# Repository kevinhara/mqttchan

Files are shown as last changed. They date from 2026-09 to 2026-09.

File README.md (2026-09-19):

# mqttchan

A desk notification device: an ESP32 with two 128x64 OLEDs — one showing an
animated avatar face, one showing message text as a typed-out speech bubble —
plus an RGB status LED and a piezo for notification jingles.

This repository holds the whole system: the firmware, the broker config, and the
services that send it messages.

```
   feeds ──HTTP──▶ services/api ──MQTT──▶ broker ──▶ firmware (the device)
(what happened)   (how it looks,        (mosquitto      (renders it)
                   how often)            on osmo)
```

| Directory | What it is |
|---|---|
| [`firmware/`](firmware/) | PlatformIO ESP32 firmware. Flash with `cd firmware && pio run -t upload` |
| [`broker/`](broker/) | mosquitto config, deployed to osmo |
| [`services/`](services/) | TypeScript: the API layer and the feeds that talk to it |
| [`docs/`](docs/) | The control page at [mqttchan.kev.nz](https://mqttchan.kev.nz), served by GitHub Pages |

## Why feeds don't publish to MQTT themselves

Feeds POST a *semantic* message to the API — "this happened, it's low priority"
— and the API alone decides how it looks and when it is shown. Nothing but the
API connects to the broker.

That split earns its keep in two places:

- **The device contract can change without touching a feed.** It already has:
  contract v2 made expressions case-insensitive and gave `led` arbitrary hex
  colors, and no feed needed to know.
- **The device is slow, and one place has to know that.** It shows one message
  at a time and holds it ~30s after typing it out, so it absorbs roughly one
  message per 35 seconds — and its own queue is unbounded, so once you overrun
  it, it never catches up. The API paces publishes to the device's real speed,
  collapses repeated readings of the same thing, drops stale messages, and lets
  genuine alerts jump the queue.

## Status

Built, deployed and verified on hardware 2026-09-17:

- **Contract v2 is flashed and verified on the device** (`Ziggy`, `10.0.0.114`).
  Firmware is at 45.8% of the 3MB app partition. Checked against serial with a
  negative control, so silence means parsed rather than merely unobserved:

  | Payload | Serial |
  |---|---|
  | `happy` + `#ff8800` + `Chime` | silent — v2 forms all parse |
  | `Happy` + `red` + `chime` | silent — the old spellings still work |
  | `sleepy` + `cycle` | silent |
  | `ecstatic` + `#fff` + `kazoo` | all three warned and fell back |

  The `#fff` rejection is deliberate: only the exact 6-digit form parses, so a
  typo warns instead of being guessed at.
- **`services/api` is deployed on osmo** (`mqttchan-api`, port 8420) and
  connected to the broker. Verified publishing valid v2 payloads with pacing,
  dedupe by key, and high-priority messages overtaking queued ambient ones.
- **The Python `avatar-brain` container has been stopped and removed** from
  osmo. Its source directory is left at `~/avatar-brain` there, so the
  decommission is reversible.
- 52 unit tests passing across the API, feed-kit and the flights feed.

**The first real feed is live: `feeds/flights`**, which announces arrivals and
departures at ZQN from live ADS-B. Deployed to osmo as `mqttchan-feed-flights`
and **confirmed end to end on real traffic 2026-09-18**: at 09:20 NZST it
published `ZKICH left ZQN` — one message, no duplicate, queue drained, device
connected throughout. The API paced and published it unchanged, and triage
rendered `kind: "notice"` as
`{"expression":"happy","led":"#3399ff","blink":false,"jingle":"chime"}`.

The detector was also validated offline against a real arrival before deploy: a
captured 15-snapshot approach (ANZ611 descending 5550ft at 11.8nm through to
on-the-ground at 0.27nm), replayed, announces `ANZ611 landed at ZQN` exactly
once and stays silent either side of it.

**Correction, 2026-09-18 (same day):** the line above briefly said a departure
was "not yet seen live", which was true for about twenty minutes after deploy.
`ZKICH left ZQN` settled it. Both directions of the edge are now confirmed
against real aircraft, which is worth stating plainly because the departure
path is the one that had only unit tests behind it.

**Correction, 2026-09-18:** this section previously said the first real feed
would be Home Assistant temperature readings. That was the plan and the HA
research had already been done; the flights feed was simply what got built
first. The HA work is still queued and still valid — see
[`services/README.md`](services/README.md).

**Correction, 2026-09-19:** contract v3 removed `expression` entirely — the
`happy`/`angry`/`sad`/`doubt`/`sleepy`/`neutral` vocabulary above and the
`{"expression":"happy",...}` triage output a few lines up are v2 history, not
current behavior. The field had already stopped doing anything the moment the
firmware's portrait pack replaced m5avatar's procedural eyes/mouth (contract
v2's expressions had nowhere left to apply); v3 just stopped sending and
validating it. `led`, `blink` and `jingle` are unaffected.

`feeds/example` remains a template, left disabled behind a compose profile.

## Deploy

```
cd firmware && pio run -t upload                      # the device
scp -r broker kevin@osmo:~/mosquitto                  # the broker
scp -r services kevin@osmo:~/mqttchan-services        # the API and feeds
ssh kevin@osmo 'cd ~/mqttchan-services && docker compose up -d --build'
```

`services/.env` is not in git — copy `services/.env.example` on the host and
fill it in.

## History

The broker config and a Python publisher called `avatar-brain` used to live in
`~/Homelab/osmo/`, which is not a git repository. Both moved here on
2026-09-17: the broker config unchanged, and `avatar-brain` superseded rather
than migrated — it had been running on osmo for weeks in a dormant state, with
no entities configured and an expired token, and had never published anything.
Stubs in the old Homelab directories point here.

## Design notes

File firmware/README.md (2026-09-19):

# mqttchan firmware

**Moved 2026-09-17** from the repository root into `firmware/`, when the
firmware, the broker config and the new TypeScript services were collapsed into
one monorepo. Nothing in the build changed — but **the flash command is now
`cd firmware && pio run -t upload`**, not `pio run -t upload` from the repo root.
Paths quoted throughout this file (`include/...`, `src/...`) are still relative
to this directory and remain correct; `../docs/index.html` is the exception,
since the control page stays at the repo root for GitHub Pages.

This file used to be titled "avatar-demo", after the project this started as.
The device is called mqttchan; `avatar/say` remains the MQTT topic.

**Correction, 2026-09-18:** this file used to say `m5stack-avatar` "remains
the rendering library" and described the face panel throughout as procedural
eyes/mouth driven by `Avatar::setExpression()`/`setMouthOpenRatio()`. That's
no longer true: the face panel now shows a random bitmap portrait from the
bundled "1-bit dialogue portraits" pack instead (`include/portrait_face.h`,
`include/portraits_data.h`) - a slow "breathing" bob while idle, punctuated
every few seconds by a quick blink (added 2026-09-19). Every character
blinks, using the exact same mechanism for all 99: `Portrait::blink`, a
frame `firmware/tools/gen_portraits.py` synthesizes for every character
(`_SYNTHETIC_BLINKS`, one dict entry per character) by closing an eye region
hand-picked against that character's own art and cutting a thin line back
through it - kept entirely separate from the pack's own `frames`/
`frameCount`, which are unchanged and still only drive the talk-time mouth
flap (`advanceTalkFrame()`).

**Correction, same day:** two earlier passes at this got it wrong before
landing here. First pass gave the two single-frame characters (44/portrait
112, 66/portrait 156) a head-nod instead of a blink, since they had no
second frame to flash to - not what was asked for. Second pass "fixed" that
by synthesizing a real second frame for just those two, but left every other
character blinking by flashing to its own frame 1 - which, on a live board,
turned out to be a mouth-open frame for a large fraction of the pack, so
idle was visibly opening its mouth instead of blinking. Every character now
gets a synthesized `blink` frame, not just the two that had no frame 1 to
reuse in the first place - the reuse was the bug, not just the exception
list around it. Cycles through that character's own 1-4 talk frames while a
message types, and a new random character is picked each time an
announcement finishes. Build-verified and QA'd via a rendered contact sheet
of all 99 blink frames against their originals - not yet looked at on the
board. `m5stack-avatar`
and its `Avatar.h`/`SmallOledFace` are gone from the build entirely
(`platformio.ini`'s `lib_deps` no longer pulls it in). The old reading was
believable because it was true from this project's start through
2026-09-17 - this is a deliberate swap, not a regression. The rest of this
document (core split, MQTT contract, expressions, demo mode) was written
against the old library and has not been fully re-verified against the new
one; `include/portrait_face.h`, `include/mqtt_link.h` and `src/main.cpp` are
the current source of truth where the two disagree. **Update, 2026-09-19:**
"expression" no longer appears in the MQTT payload at all - contract v3
removed the field entirely (it had been parsed-and-warned-on but otherwise
inert since the portrait swap above; see **Contract v3** under "MQTT-driven
mode" below).

[stack-chan/m5stack-avatar](https://github.com/stack-chan/m5stack-avatar) used
to run on a bare ESP-WROOM-32 with a 128x64 SSD1306 I2C OLED — no M5Stack
hardware involved; see the correction above for what replaced it. A second
SSD1306 shows what's "said" as a word-wrapped speech bubble (see "The speech
bubble" below) — optional, and everything below runs fine without it wired
up.

By default the board joins WiFi, subscribes to an MQTT topic, and drives the
avatar + bubble from whatever `{"text":..., "led":..., ...}` JSON arrives
(see "MQTT-driven mode" below, including **Contract v3**'s removal of
`"expression"`) — this is meant to run against the `services/api` layer in
this repo, not standalone. (It previously ran against a Python `avatar-brain`
service in the homelab; that has been superseded — see the root README.)
Build with `-DAVATAR_DEMO_MODE` instead to get the old self-cycling bench
demo (cycles six placeholder phrases, fakes lip-sync babble on every third
one) with no network required.

Verified live 2026-09-14 on ESP32-D0WDQ6 rev v1.0 (`/dev/cu.usbserial-0001`):
demo mode renders all six expressions correctly, heap flat at ~295 KB across
9 cycles, no reboots. MQTT mode verified the same day via the headless bench
test described below (no live broker was up yet): WiFi correctly times out
and retries rather than hanging when `secrets.h` has placeholder credentials,
and a synthetic payload correctly renders both the Happy expression and a
two-line-wrapped bubble.

## Core split

This was the reason for building it — the avatar gets one core, the other
stays free for application work.

| Core | Owner | What runs there |
| --- | --- | --- |
| 1 (`APP_CPU`) | the avatar | `drawLoop` + `facialLoop` (blink, saccade, breath) |
| 0 (`PRO_CPU`) | you | `appTask` — triggers, TTS, LLM calls, network |

The library already does most of this: `Avatar::start()` hardcodes both of its
tasks to `APP_CPU_NUM`, so no patching was needed. The part that _is_ on us is
that Arduino's `loop()` also runs on core 1 — so `loop()` is deliberately left
empty and all app logic goes in `appTask`, pinned to `PRO_CPU_NUM`. Putting
work in `loop()` would quietly land it on the avatar's core and fight the
renderer for time.

Cross-core calls into the avatar are safe for what the demo uses:
`setExpression()` suspends the draw task before mutating, and the float
setters (`setMouthOpenRatio`, gaze, breath) are single-word writes the draw
task only reads.

## Wiring

Two SSD1306 panels, **each on its own I2C bus** — they don't share pins:

| Panel | SDA | SCL | VCC | GND | Bus |
| --- | --- | --- | --- | --- | --- |
| Face (`oled`) | GPIO32 | GPIO33 | 3V3 | GND | software (bit-banged) I2C |
| Bubble (`oledText`) | GPIO4  | GPIO15 | 3V3 | GND | hardware I2C port 1 |

Both panels answer at the default address **0x3C** — no jumper needed, since
they're on physically separate buses and there's nothing to collide with.

**Corrected 2026-09-15:** this table used to pair Face with GPIO4/15
(hardware bus) and Bubble with GPIO32/33 (bit-banged) — the two physical
panels turned out to be mounted reversed relative to that wiring, so content
was landing on the wrong screen. `main.cpp` now builds `oled` on the
GPIO32/33 pins and `oledText` on GPIO4/15 instead (see the comment above
their declarations), which is the swap reflected in the table above. The
GPIO-level facts below (which pins to avoid and why) are about the physical
pins themselves and didn't change — only which panel/content each pin pair
drives did. Net effect: the avatar now runs on the slower 400kHz bit-banged
bus instead of the 800kHz hardware one; re-wiring instead of swapping in
software would recover that speed, but wasn't done here.

**Do not move GPIO4 (now the bubble panel's SDA) to GPIO2.** GPIO2 is a
boot-strapping pin; the OLED's pull-up on it holds the ESP32 out of USB
download mode (`Wrong boot mode detected (0x1b)`) and flashing fails whenever
the display is attached. Same lesson the sibling `hello-world` panel learned
on 2026-09-14. Port 1 (now the bubble panel's bus) is likewise deliberate:
M5Unified's `begin()` claims port 0 for its own PortA devices, and sharing it
means two drivers reconfiguring one peripheral with different pins.

**Why one panel is on GPIO32/33 instead of a second hardware port:** the
ESP32 classic only has two hardware I2C peripherals, and both are already
spoken for (port 0 by M5Unified, port 1 by the other OLED panel).
`SSD1306Display` in `ssd1306_display.h` passes its `i2c_port` argument
straight through to LGFX's `Bus_I2C`, which treats a **negative** port number
as a request for its bit-banged software I2C path (`soft_i2c.inl`) on
whatever GPIOs you give it — so `oled` in `main.cpp` is constructed with port
`-1` and pins 32/33. GPIO32/33 were picked because they're not
boot-strapping pins, not the SPI-flash pins (6-11), and not already claimed
by the other OLED panel or M5Unified. Clocked at 400kHz rather than the
hardware bus's 800kHz, since bit-banged timing is CPU-cycle-bound and less
forgiving at high speed.

## RGB status LED

A 4-pin RGB LED (3 color legs + 1 common leg), wired straight to the ESP32 —
no driver board, just a resistor per color leg.

| Leg | GPIO | Resistor  |
| --- | --- | --- |
| Red | GPIO25 | ~150–220Ω |
| Green  | GPIO26 | ~220–330Ω |
| Blue | GPIO14 | ~220–330Ω |
| Common | GND | none |

**Verified live 2026-09-16** on the same `/dev/cu.usbserial-0001` board:
wired common-cathode (common leg to GND), all three legs confirmed against
their GPIO via the `RGB_LED_TEST` build below — red/green/blue/off cycle and
a full HSV spectrum sweep both rendered the correct colors with no cross-talk
between channels.

**Put one resistor per color leg, not one shared resistor on the common
leg.** Each color die has a different forward voltage (red ≈2.0V,
green/blue ≈3.0V at 3.3V logic), so a single shared resistor over- or
under-drives whichever color has a different Vf, unevenly across channels.
The common leg itself needs no resistor — it's just the return path.

**This board is a 30-pin ESP32 devkit — GPIO16/17 aren't broken out**, unlike
on 38-pin boards where they usually are. GPIO25/26/14 were picked instead:
all three drive over LEDC PWM, and none collide with the OLED buses
(GPIO4/15, GPIO32/33), the piezo (GPIO27), the boot-strapping pins
(0/2/5/12), or M5Unified's reserved PortA pins (21/22 — see the comment in
`ssd1306_display.h`).

**If the LED turns out common-anode instead** (common leg to 3V3, not GND),
don't rewire it — `#define RGB_COMMON_ANODE` above the pin defines in
`main.cpp` inverts the PWM duty cycle in software instead.

**Building/rewiring on a breadboard-free case:** with Dupont jumpers jammed
straight into the 3D-printed case rather than a breadboard, splice each
resistor into its own jumper wire (cut a female-to-female wire in half,
twist/solder the resistor lead to the bared end, heat-shrink the joint) —
keeps the same connector style as the rest of the wiring rather than
introducing a different mechanical fit.

A standalone wiring-test build lives behind a flag rather than in the real
app, same pattern as `AVATAR_DEMO_MODE`/`AVATAR_FB_DUMP` below — see
`RGB_LED_TEST` in `main.cpp`. Build/flash it with:

```
PLATFORMIO_BUILD_FLAGS="-D RGB_LED_TEST" pio run -e esp32dev -t upload
```

It replaces `setup()`/`loop()` entirely (no WiFi/MQTT/avatar involved):
cycles red → green → blue → off at full brightness (0.7s each, with serial
prints), then sweeps a full 360° HSV rainbow at ~15ms/step. Reflash without
the flag (`pio run -e esp32dev -t upload`) to return to the real app.

**In the real (non-`RGB_LED_TEST`) app, the LED is message-driven.** A
message payload's optional `"led"` field (`"red"`/`"green"`/`"blue"`/
`"cycle"`) and optional `"blink"` boolean (default `false`) — see "MQTT-driven
mode" below — light `include/rgb_led.h`'s `RgbLed` for exactly as long as
that message is on the bubble panel (typing + hold, or indefinitely under
`keepLastMessage`), then it turns off along with the bubble reverting to the
idle clock. `"cycle"` sweeps the same HSV rainbow as the wiring test above;
`"blink"` toggles whatever color is active (solid or cycling) on/off every
400ms. An unrecognized `"led"` string logs a warning and leaves the LED off
for that message, same "falls back rather than fails" treatment as an
unrecognized `"jingle"`. Not yet verified live against a real message
flow — the wiring test above confirmed the physical LED itself, but this
message-driven path has only been build-verified so far.

## The speech bubble (second panel)

`include/speech_bubble.h`'s `SpeechBubble` class draws a bordered,
word-wrapped text box to a second panel — `oledText` in `main.cpp` — kept
completely separate from the avatar's own `M5.Display`. Text is revealed one
character at a time (`show()`'s `charDelayMs`, default 25ms/char) rather than
appearing all at once, so it reads as the character actually talking. This
blocks `appTask` for the reveal's duration (~strlen \* charDelayMs) — fine
here since nothing else needs that core's attention mid-phrase, but worth
knowing if something latency-sensitive ever gets added to the same task.
`appTask` calls `bubble->show(...)` with a canned phrase alongside each
demo-loop pass; swap that call for real TTS output text and nothing else
needs to change. The canned phrases (`kPhrases` in `main.cpp`) are nihilistic
one-liners — a demo bubble should at least be funny.

Status: verified live 2026-09-14 on real hardware (both failure and success
paths). With no second panel attached, `setup()` logged `Second SSD1306
(text) init failed` exactly as designed and the avatar kept cycling normally
on the first panel. With the second panel wired to GPIO32/33 per Wiring above,
the framebuffer dump (`dumpBubbleFramebuffer`, under `-DAVATAR_FB_DUMP`)
confirmed the rounded-rect border draws correctly and word-wrap works: short
phrases ("Great to see you!") render on one line, and the longest phrase
("Feeling kind of blue.") correctly wraps to two lines without overlap.

**Message text size is configurable** (`SpeechBubble::setTextSize()`,
persisted as `DeviceSettings::messageTextSize`/`textSize` over BLE): "Small"
(the original size, value `1`) is the default, "Large" (value `2`) doubles
both glyph dimensions. Changeable from the control page's Messaging settings
group (`../docs/index.html`) same as message hold time/keep-last-message; takes
effect on the next message shown, not retroactively on whatever's already on
screen. Not yet verified live — build-verified only so far, unlike the rest
of this section.

**Correction, 2026-09-19:** a report from the board described Large text's
second line as "garbled" once a message ran long enough to scroll. Chasing it
turned up no corruption in `SpeechBubble`'s own model: a RAM-shadow-buffer
dump (`dumpBubbleFramebuffer`) taken after a real multi-scroll run on the
board showed both visible lines cleanly separated, and the `scroll()`/
`copyRect()` math checked out by hand too. Rather than ship nothing against a
report that real, `show()` now explicitly wipes each line's own rect
immediately before drawing into it (see the comment in `speech_bubble.h`) -
cheap, safe, and it closes the most plausible gap even though the exact
mechanism wasn't confirmed. Still wants an actual look at the board to
confirm the report is gone, not just unreproduced in software.

## Screen brightness and overnight schedule

Both OLEDs power off overnight rather than showing an unread idle clock/face
all night (`MqttLink::applyScreenPower()`), and dim rather than always running
at full contrast. Three settings, all in `DeviceSettings`/persisted over BLE
the same way `messageTextSize`/`holdSeconds` are, control this:

| BLE field | Type | Meaning |
| --- | --- | --- |
| `brightness` | `uint8_t`, 0-100  | Panel contrast, as a percentage (`MqttLink::applyBrightness()` maps this onto the SSD1306 contrast register's 0-255 range). |
| `screenOffStart`  | `uint16_t` | Minutes since midnight, local time, when both panels power off. |
| `screenOffEnd` | `uint16_t` | Minutes since midnight when they power back on. Wraps across midnight when `screenOffStart > screenOffEnd` (e.g. 22:00-07:00); setting the two equal disables the schedule entirely - the panels never power off on their own. Defaults to `0`/`420` (00:00-07:00), matching this feature's original hardcoded window. |
| `wakeForMessage`  | `bool` | Whether an incoming message wakes sleeping panels (default `true`, the original behavior). When `false`, a message during the off window is still typed and held as normal, just onto panels that stay powered down - it shows once they next wake on their own. |

Deliberately independent of `isNighttime()`'s fixed 23:00-07:00 window, which
only controls the resting face's sleepy expression, not panel power - the two
don't have to (and by default don't) share a boundary.

Changeable from the control page's new Screen settings group
(`../docs/index.html`) - a brightness slider and two `<input type="time">`
fields, converted to/from minutes-since-midnight at the BLE read/write
boundary (see `minutesToTimeStr()`/`timeStrToMinutes()` there).

**Verified live 2026-09-19** on the board (`Ziggy`, `10.0.0.114`,
`/dev/cu.usbserial-0001`): flashed clean, booted with WiFi/MQTT/BLE all
connecting normally (no regression from the pre-existing hardcoded
midnight-07:00/full-brightness/always-wake behavior, since the new settings'
defaults reproduce it exactly). The BLE config contract itself was exercised
directly (Python + `bleak`, not the control page) - wrote
`{"brightness":40,"screenOffStart":1350,"screenOffEnd":375,"wakeForMessage":false}`,
read the config characteristic back and got those exact values, confirming
the write persists to NVS and round-trips correctly, then restored the
defaults. Not yet confirmed by eye: that 40% actually looks dimmer on the
physical panel, or that the schedule/wake-gating logic behaves correctly
across a real midnight boundary - both are logic-verified (the mapping math,
the wraparound comparison) but not eye/clock verified.

## How it was made to work on a non-M5 panel

Two problems had to be solved; both are worth knowing before editing this.

**1. The avatar only draws to `M5.Display`.** `Face.cpp` references `M5.Lcd` /
`M5.Display` directly — there is no "render to an arbitrary canvas" entry
point. So the fix is to make M5Unified's primary display _be_ the SSD1306.
M5GFX ships `lgfx::Panel_SSD1306` but no device wrapper for it (only
`M5UnitOLED`, which is an SH110x 64x128), so `include/ssd1306_display.h` is
that wrapper, written to the same shape as M5GFX's own `M5UnitOLED.h`. It is
attached with `M5.addDisplay()` + `M5.setPrimaryDisplay()`.

Ordering is load-bearing: **each panel's `.init()` must come after
`M5.begin()`.** `M5.begin()` runs M5GFX board autodetect, which probes SPI
pins — GPIO15 among them. Since the 2026-09-15 pin swap (see Wiring above),
GPIO15 is `oledText`'s SCL, not `oled`'s, so this now bears on
`oledText.init()` rather than `oled.init()` — but both already run after
`M5.begin()`, so the requirement is satisfied either way. Initialising a
panel afterwards re-owns whatever pins it uses and sends the SSD1306 its full
reset sequence. The other order leaves the panel blank.

**2. The stock face is drawn for a 320x240 canvas.** `m5avatar::Face` puts the
eyes at x=90/230 and the mouth at y=148; the library's own `faces/OledFace.h`
is in the same coordinate space despite its name, so it is not the answer
here. Using `Avatar::setScale()` to shrink 320x240 into 128x64 works but looks
bad — on a 1-bit panel there is no grey to antialias a downscale into, so the
eyes come out as ragged blobs. `include/small_oled_face.h` instead authors the
geometry at 1:1 for 128x64.

When editing that geometry: every position is the **centre** of its part, not a
corner, and `BoundingRect` takes **(top, left)** — y first. `Eye` reads
`getCenterX/Y()` while `Mouth` and `Eyeblow` read `getLeft/getTop()`; the
two-arg `BoundingRect` leaves width/height at 0, which is what makes those
agree.

## Seeing what the panel shows, without looking at it

Build with `-DAVATAR_FB_DUMP` and the panel framebuffer gets dumped to serial
as ASCII art (`Panel_HasBuffer` keeps a readable RAM copy, so this reads back
what was actually rasterised, not what was intended) — after each phrase
change in demo mode, or once after the synthetic bench-test payload in MQTT
mode (see "MQTT-driven mode" above). It costs nothing when the flag is off,
which is the default. This is how every "verified live" claim in this file
was checked.

```
pio run -t upload                                              # MQTT mode (default)
PLATFORMIO_BUILD_FLAGS="-DAVATAR_DEMO_MODE" pio run -t upload   # demo mode, no network
PLATFORMIO_BUILD_FLAGS="-DAVATAR_FB_DUMP" pio run -t upload     # + framebuffer dump
```

Note `pio device monitor` fails in a non-TTY shell (`termios.error: (19,
Operation not supported by device)`) — read the port with pyserial instead.

## Boot screen and splash

Every power-up now opens with the HLI boot POST + splash intro — ported
verbatim from `~/Code/esp32_oled/HLI` (`include/boot.h`+`src/boot.cpp`,
`include/splash.h`+`src/splash.cpp`, `include/ui.h`+`src/ui.cpp`,
`include/brand.h`) — before `M5.begin()` hands both panels to the avatar and
the clock. Both are pure functions of elapsed ms plus a `U8G2&`, with no
app/network dependency, so they carried over unmodified; only `main.cpp`
changed.

**Splash plays on the face/top panel, POST plays on the bubble/bottom
panel, concurrently** — not the same sequence on one panel, back to back.
The synthwave splash is the flashy full-frame graphic, so it runs where the
avatar lives afterward; the POST is scrolling console text, so it runs where
the clock's own text lives afterward. Two separate `U8G2` instances in
`main.cpp` do this: `u8g2Face` (hardware I2C, same GPIO4/15 as `oled`) draws
`splash::draw()`, `u8g2Boot` (software/bit-banged I2C, same GPIO32/33 as
`oledText`) draws `boot::draw()`, both inside one `while` loop in `setup()`.
Because POST (6.47s) outlasts the splash intro (4.78s), the loop keeps
running boot alone for the last ~1.7s while the splash side just holds its
settled final frame — total added boot time is POST's own length, not the
sum of both.

They draw through U8g2's own I2C drivers rather than through
`ssd1306_display.h`'s LGFX wrapper: porting `boot.cpp`/`splash.cpp`'s ~40 raw
`U8G2` draw calls (XOR bars, dot leaders, a hand-drawn 32px glyph, the
5x-pixel outrun grid) to LGFX wasn't worth it for a sequence that plays once
and hands off.

**Two different I2C drivers share each pair of pins, one after the other,
not at once.** `u8g2Face`'s Arduino HW-I2C backend drives GPIO4/15 via
`Wire` (I2C_NUM_0); `SSD1306Display` (`oled`) drives the same pins via
LGFX's `Bus_I2C` on I2C_NUM_1. `Wire.end()` right after the boot/splash loop
releases I2C_NUM_0 before `M5.begin()` + `oled.init()` reclaim the pins on
I2C_NUM_1 — the same "ordering is load-bearing, pins get re-owned" pattern
the M5.begin()-then-oled.init() sequence below already relies on, just one
hop earlier. `u8g2Boot`'s software I2C on GPIO32/33 needs no equivalent
release: bit-banging is plain `digitalWrite()`, so there's nothing left
running for `oledText.init()` to contend with once the loop exits.

`olikraus/U8g2 @ ^2.35.30` was added to `lib_deps` for this.

**Correction, 2026-09-15:** this section originally said the single `u8g2`
instance was built at `U8G2_R2` "to match `M5.Display.setRotation(2))`" and
that boot+splash ran sequentially on one panel over ~11.2s. Both were wrong
in ways only visible with eyes on the actual panel: U8g2's rotation and
LGFX's `rotation(2)` don't agree for this SSD1306 driver/panel combination,
so `U8G2_R2` rendered upside down despite matching the avatar's own
rotation — `U8G2_R0` is correct here. And splitting boot/POST onto their own
panels (this section, same date) made "sequential on one panel" moot. The
old reading was believable because U8g2's `U8G2_R2` and LGFX's
`setRotation(2)` share the same "180 degrees" name; they just don't rotate
the same panel the same way.

**A single DOS-BIOS-style POST beep** fires on the piezo (`PIEZO_PIN`,
GPIO27) the instant the POST side finishes — `tone(PIEZO_PIN, 1000, 150)` in
`main.cpp`'s boot/splash loop, gated on a `posted` flag so it fires exactly
once regardless of how much longer the splash side keeps running. This is
the classic "self test passed, handing off to the bootloader" chime
(AMI/Award BIOSes: one short beep = good), not a beep per POST line — real
BIOSes are silent through the self test and only speak once, at the end.

Verified live 2026-09-15 on the same board as above: `pio run` builds clean
at 45.5% flash / 19.9% RAM (up ~0.1% from the single-panel version above —
the second `U8G2` instance costs one more small framebuffer + driver
instantiation, nothing more). `pio run -t upload` flashed successfully.
Three separate DTR/RTS-reset serial captures landed "WiFi: connecting..."
at 14.87-14.88s (down from the old sequential design's ~17.5s, consistent
with POST-only being ~4.8s shorter than POST+splash-in-series). One of the
three captures crashed instead, at the MQTT-connect step, on an lwIP assert
(`udp_new_ip_type ... Required to lock TCPIP core functionality`) — nothing
in this change touches networking, and the other two resets (before and
after it) completed cleanly, so this reads as pre-existing intermittent
flakiness rather than something introduced here, but it's noted rather than
swept under the rug in case it recurs. The panel's actual pixels weren't
eyeballed as part of this check (no camera on this session) — worth a glance
next power-up to confirm the split/orientation actually reads as intended,
given the rotation correction above came from exactly that kind of miss.

**Correction, 2026-09-16: the beep now fires at the _start_ of POST, not the
end.** The paragraph above described a single beep firing "the instant the
POST side finishes," modeled on the AMI/Award "self-test passed" chime at
hand-off to the bootloader. On reflection the beep these old boot screens are
actually remembered for is the one that opens the self test, not the one that
closes it, so `main.cpp`'s boot loop now fires `tone(PIEZO_PIN, 1000, 150)`
once, immediately after `boot::begin()` and before the loop's first
`boot::draw(u8g2Top)` call — not when `boot::done()` goes true. `bootDone`/
`bootDoneAt` still exist and still gate `PHASE_HOLD_MS`; they just no longer
also gate the beep. Not re-verified live since this only moves _when_ an
already-verified `tone()` call fires, not what it does.

**Correction/update, 2026-09-16:** three more changes, made on feedback from
actually looking at the panel — proof the "worth a glance" note above was
right to flag.

- **POST and splash swapped panels.** POST now plays on the top/face panel
  (`u8g2Top`, was `u8g2Face`), splash on the bottom/bubble panel
  (`u8g2Bottom`, was `u8g2Boot`) — the reverse of what this section said
  above. The two `U8G2` instances in `main.cpp` are now named for physical
  position, not content, since content has already moved once.
- **The loop no longer freezes either sequence once it individually
  finishes.** Previously, `splash::draw()` only got called while
  `splash::intro()` was true, so once its 4.78s intro ended (before POST's
  6.47s did) it froze on the settled title-card frame instead of falling
  into its own attract loop (kicker lines cycling, scan bar sweeping).
  Both sides now draw every frame unconditionally, and a `POST_HOLD_MS`
  (2000ms) constant keeps the loop running for a further beat once _both_
  are done, specifically so that attract-loop motion — and POST's cursor
  still blinking — are actually visible before `M5.begin()` takes the
  panels, rather than the app moving on the instant the longer sequence's
  one-shot ends.
- **POST's console font changed** from `u8g2_font_4x6_tf` to
  `u8g2_font_5x8_tf`, to match mqttchan's own "message screen"
  (`SpeechBubble`'s font — LGFX's default, the classic 5x7-glyph/6x8-cell
  GLCD font, see `speech_bubble.h`) instead of the original HLI source
  project's tighter one. This shrank the console grid from 32x10 to 25x8
  (`ui.h`'s `CW`/`CH`/`COLS`/`ROWS`); every existing BIOS/POST line in
  `brand.h` already fit under the new 25-column limit without editing
  (longest is exactly 25). Splash's own kicker-line font is untouched —
  still 4x6 — so `splash.cpp`'s one call that used to reuse `ui::CH` for
  its static-noise band height now uses a literal `6` instead, so it didn't
  drift when the shared constant it borrowed changed size for an unrelated
  reason.

Verified live 2026-09-16 on the same board: `pio run` builds clean at 45.5%
flash / 19.9% RAM (unchanged from the numbers above to one decimal place).
`pio run -t upload` flashed successfully; a DTR/RTS-reset serial capture
landed "WiFi: connecting..." at 17.89s (up from 14.87-14.88s above by
almost exactly `POST_HOLD_MS`'s 2000ms, as expected), then through to "MQTT:
connected and subscribed" / "BLE: advertising" with no crash. Panel pixels
still weren't eyeballed this round either (still no camera on this
session) — this entire update exists _because_ a human did look at the
previous round, so that glance is doubly worth doing again here.

**Correction, 2026-09-15: the two physical panels turned out to be mounted
reversed** relative to all of the pin numbers above — a hardware fact, not a
content-placement choice like the 2026-09-16 swap above. `u8g2Top` and `oled`
(the "top/face" role) now run on GPIO32/33 (software/bit-banged I2C, so
`u8g2Top` changed from the `HW_I2C` template to `SW_I2C`); `u8g2Bottom` and
`oledText` (the "bottom/bubble" role) now run on GPIO4/15 (hardware I2C, so
`u8g2Bottom` changed the other way). See the Wiring section above for the
corrected pin table and the trade-off this introduces (the avatar now
animates over the slower bit-banged bus). `u8g2Top`/`u8g2Bottom` keep their
physical-position names and still draw the same content (POST on top, splash
on bottom) as the 2026-09-16 section above describes — only the electrical
pins underneath moved. Not yet re-verified live on hardware; flash and check
both the boot sequence and the running avatar/bubble land on the intended
physical screen before trusting this.

**Correction/update, 2026-09-15 (later the same day): boot and splash are no
longer concurrent, and splash now plays a synthwave riff on the piezo.**
Three changes, on top of the physical-panel-reversal correction just above:

- **The shared `while` loop is gone.** `setup()` now runs POST and splash as
  two fully separate phases — POST alone on `u8g2Top` first, then (once
  `boot::done()`) splash alone on `u8g2Bottom` — rather than drawing both to
  one shared frame clock. This turned out to be why _both_ were reported
  janky, not just the slower panel: sharing one loop meant each sequence's
  own animation was throttled down to whatever pace the loop as a whole
  could sustain, which was however long the slower panel's send took,
  regardless of how fast the other one's own bus was. Whichever panel isn't
  currently playing is blanked rather than drawn to for no reason.
- **`u8g2Top` (POST, now on GPIO32/33 after the pin-reversal fix above) moved
  off U8g2's software I2C onto the ESP32's second hardware I2C peripheral**
  (`Wire1`), via U8g2's `_2ND_HW_I2C` constructor variant and a new
  `-D U8X8_HAVE_2ND_HW_I2C` build flag in `platformio.ini` (without that flag
  the constructor is a silent no-op — U8g2 only defines the macro itself on
  boards that declare `WIRE_INTERFACES_COUNT > 1`, which `esp32dev` doesn't).
  U8g2's own software I2C bit-bangs through `digitalWrite()` per bit, which
  is slow enough that sending one 1024-byte frame plausibly took tens of
  ms — independently of the shared-loop problem above, and the likely actual
  cause of POST's own reported jank. `u8g2Bottom` (splash) didn't need this:
  it already sits on GPIO4/15's real hardware peripheral (global
  `Wire`/I2C_NUM_0). `Wire1.end()` releases the peripheral before `oled`
  (LGFX, its own bit-banged path on the same GPIO32/33 pins) claims them at
  runtime — this one isn't just hygiene the way `Wire.end()` for `Wire` is,
  since a hardware peripheral left attached to those pins would otherwise
  still be driving them alongside `oled`'s plain `digitalWrite()` bit-banging.
- **Splash now plays a monophonic synthwave arpeggio on the piezo**
  (`splash::playTheme()`, called from `main.cpp`'s splash phase alongside
  `splash::draw()`) — the "retro cassette" half of a request to give the
  intro more of that vibe; the visuals were already outrun/synthwave (the
  sun, the grid, the neon skyline), and this is what makes it read as a tape
  playing rather than just a screen lighting up. A minor pentatonic scale, a
  slow rising phrase while the world assembles, a driving arpeggio through
  the approach that quickens toward the slam, a hit on the slam, and two
  resolving notes as the mark and kicker land — driven by an explicit stage
  machine (`ThemeStage` in `splash.cpp`) rather than matching beats by time
  window, since `T_MARK` falls inside the slam's own `[T_FLASH,
T_FLASH+D_FLASH)` window and a naive time-window match would double-fire
  the slam beat instead of the mark beat.

**Correction, 2026-09-19:** a report described the screen showing leftover
content from the previous session after restarting from software (upload, or
any reset that doesn't cut power) rather than a real power cycle. Both
`u8g2Top` and `u8g2Bottom` are now explicitly blanked (`clearBuffer()` +
`sendBuffer()`) right after `begin()`, before either script's first frame -
previously only `u8g2Bottom` got this, on the reasoning that `boot::draw()`'s
own per-frame clear would blank `u8g2Top` within its first ~16ms anyway. That
reasoning covers the _shadow buffer_ the two libraries think they're showing,
not the SSD1306's own GDDRAM, which stays powered (and keeps whatever was in
it) across exactly this kind of reset - there's no way for this code to read
that back and confirm it's actually clear, hence blanking explicitly rather
than trusting the timing. The app-mode `oledText` panel got the same
treatment (an explicit `fillScreen()` after `init()`, matching what `oled`
already had) for the same reason. Not confirmed against the actual reported
symptom - this session has no camera, and the fix is defensive against every
plausible read of "restart from software," not a targeted patch for a
diagnosed single cause.

**Corrected 2026-09-19:** this used to say `pio run` builds clean at 45.6%
flash / 19.9% RAM. Measured again today (contract v2 build plus the blink,
beep, line-height and boot-clear changes above): **48.8% flash / 20.0% RAM**
(1,534,083 / 3,145,728 bytes flash, 65,452 / 327,680 bytes RAM). The old
number was believable because it was true at the time — flash usage just
grows as features do, and 3.5 points isn't the kind of jump worth digging
into.

Verified live 2026-09-19 (same board, `Ziggy`, `10.0.0.114`): `pio run -t
upload` flashed successfully, and a DTR/RTS-reset serial capture reached
"WiFi: connected" → "MQTT: connected and subscribed" → "BLE: advertising"
with no crash - same result as the 2026-09-15 check below, re-run after this
session's changes rather than assumed still true.

Verified live 2026-09-15: `pio run -t upload` flashed successfully. Two
back-to-back DTR/RTS-reset serial captures both reached "WiFi: connected" →
"MQTT: connected and subscribed" → "BLE: advertising" with no crash. One of
the two captures logged a single early transient:
`[900][E][esp32-hal-i2c-ng.c:275] i2cWrite(): i2c_master_transmit failed:
[259] ESP_ERR_INVALID_STATE`, right around when `u8g2Top`'s POST console
would be sending its first frames over the new `Wire1` path — the other
capture didn't show it at all, so it's intermittent rather than
deterministic, and in both runs the board carried on and booted cleanly
regardless. Plausibly a one-off hiccup on `Wire1`'s very first transaction
after `Wire1.begin()`, harmless in practice since U8g2 resends the whole
POST frame every ~16ms anyway — a single dropped frame in a several-hundred-
frame sequence would be invisible. **Not confirmed by eye yet** — this
session has no camera, so whether POST/splash actually read as smooth, and
whether that intermittent error ever shows up as a visible glitch on the
panel, still wants an actual look at the hardware next time someone's near
it. The synthwave riff likewise hasn't been listened to yet.

## MQTT-driven mode

Default build (no flags). `include/mqtt_link.h`'s `MqttLink` owns WiFi +
MQTT: connects, subscribes to one topic, and on every message parses
`{"text": "...", "led": "...", "blink": ..., "jingle": "..."}` JSON (see
**Contract v3** below for `"expression"`'s removal from this shape) and
calls `avatar.setExpression()` + `bubble->show(text)` straight from the
PubSubClient callback — safe here because that callback already runs inside
`mqttLink.loop()` on core 0/`appTask`, the same task that owned those calls in
demo mode, and `setExpression()` already suspends the draw task internally.
No queue needed for a single-producer, single-consumer, already-single-task
design.

**Contract v2, 2026-09-17** — two fields changed. Both changes are backward
compatible, so nothing that published to this device before needs updating.

`"expression"` is now matched with `strcasecmp` rather than `strcmp`, so
**lowercase is the canonical spelling** (`happy`, `angry`, `sad`, `doubt`,
`sleepy`, `neutral`) and the capitalized forms still work. Previously a payload
saying `"happy"` silently fell back to `Neutral` and logged a warning, which was
an easy trap for a publisher to fall into.

`"led"` and `"blink"` are both optional. `"led"` picks the RGB status LED's
color for as long as this message is on screen. It used to be one of four fixed
strings; it now accepts:

| Value | Effect |
| --- | --- |
| `""` / omitted | LED stays off |
| `"#RRGGBB"` (or `RRGGBB`) | any color — this is what the control page's picker sends |
| `"cycle"` | slow HSV rainbow sweep, as before |
| `"red"` / `"green"` / `"blue"` | kept as aliases for the full-scale primaries |

Matching is case-insensitive. Only the exact 6-digit hex form parses — a short
`#fff` logs a warning and leaves the LED off, rather than being guessed at.

`"jingle"` was made case-insensitive in the same change. It is not otherwise
altered — being the one remaining field that cared about case would have been a
trap rather than a convention.

**Contract v3, 2026-09-19 — `"expression"` is gone.** The six-word mood
vocabulary below (`happy`/`angry`/`sad`/`doubt`/`sleepy`/`neutral`) stopped
driving anything the moment the portrait pack replaced `m5stack-avatar`'s
procedural eyes/mouth (see the correction near the top of this file) — it had
been a parse-and-warn-only no-op field since. `MqttLink` no longer reads the
key at all: `doc["expression"]` is gone from `parseMessage()`, so a publisher
that still sends it is unaffected (the key is simply ignored, same as any
other unrecognized JSON field) but no longer gets the "unrecognized
expression" warning on the serial log either, since there's nothing left to
recognize against. Backward compatible in the sense that nothing breaks;
not backward compatible with anything that was reading that warning as
signal. `"led"`, `"blink"` and `"jingle"` are unchanged by this.

**Verified live 2026-09-17** (contract v2, when `"expression"` still parsed
and warned — see the v3 note above for its removal) on the board (`/dev/cu.usbserial-0001`, device name
`Ziggy`, `10.0.0.114`), by publishing to `avatar/say` and reading the serial log.
A negative control was included deliberately, so that a silent log means "parsed"
rather than "nothing was watching":

| Published | Serial output |
| --- | --- |
| `{"expression":"happy","led":"#ff8800","jingle":"Chime"}` | silent — all three v2 forms parse |
| `{"expression":"Happy","led":"red","jingle":"chime"}` | silent — pre-v2 spellings still work |
| `{"expression":"sleepy","led":"cycle"}` | silent |
| `{"expression":"ecstatic","led":"#fff","jingle":"kazoo"}` | all three warned and fell back |

Note the `#fff` case: shorthand hex is **not** accepted, by design. Both the
typing/LED behaviour on the panels and the color accuracy of a mixed hex value
were not checked by this test — it confirms parsing, not rendering.

**Arbitrary colors are approximate, not calibrated.** The per-channel resistors
are deliberately unmatched (see "RGB status LED" above), because the color dies
have different forward voltages. Full-scale primaries look right; mixed colors
are in the right area and white comes out tinted.

`"blink"` (default `false`) toggles whichever color is active on/off every 400ms
instead of holding it solid. See `include/rgb_led.h` for the implementation —
`LedSpec` there carries explicit 8-bit channels, which is what made hex a small
change: `write()` already drove three LEDC channels at 8-bit duty, so the old
four-value enum was the only thing in the way.

`"jingle"` is also optional and picks a short notification tune to play on
the piezo (`PIEZO_PIN`) right as the message starts showing, before its text
begins typing — `"chime"`, `"alert"`, `"fanfare"`, `"gentle"`, `"boarding"`,
`"beep"`, `"coin"`, `"oneup"`, `"stageclear"`, `"descend"`, or `"trill"`; omit
it (or leave it `""`, the default) to play nothing. Each tune runs
synchronously and finishes in well under a second, so it never overlaps
`beepChar()`'s own per-character tone() calls on the same pin. An unrecognized
`"jingle"` string logs a warning and plays nothing, same fallback as
`"led"`. See `include/jingle.h` for the note tables.

**`"coin"`/`"oneup"`/`"stageclear"`/`"descend"`/`"trill"` (added 2026-09-19)**
round out the catalog beyond what any kind currently uses — see
`services/api/src/triage.ts`'s `BY_KIND` for what's actually wired up today.
`coin`, `oneup` and `stageclear` are Mario Bros SFX transcribed by ear (not
from a reference), close enough to read as "that game" on a piezo buzzer.
`descend` mirrors `gentle`'s soft rise as a soft fall, for a "resolved/cleared"
occasion; `trill` is a busier two-note alternation for "worth a second look."
None of the five are wired to a kind yet — built and flashed to confirm they
compile and play, not chosen for anything. Not yet verified live via MQTT
(no `avatar/say` publish/serial-log round trip done for these five, unlike
the `boarding`/`beep` tables above).

**`"boarding"` (added 2026-09-18)** is a discreet two-tone "bing-bong" played
twice — the shape of a real airport PA chime, short and unhurried rather than
urgent. It is the API's default jingle for `kind: "notice"` (see
`services/api/src/triage.ts`), which today only the flights feed sends, so in
practice it plays for every aircraft arrival and departure.

**Verified live 2026-09-18** on the same board (`/dev/cu.usbserial-0001`,
`Ziggy`, `10.0.0.114`), same method as the 2026-09-17 table: publish to
`avatar/say`, read the serial log, negative control included.

| Published | Serial output |
| --- | --- |
| `{"jingle":"boarding",...}` | silent — parsed, tune plays |
| `{"jingle":"kazoo",...}` | warned and fell back, same as before |

This confirms parsing and that a tune plays, not what it sounds like through
the piezo — nobody listened to the board for this check, so "discreet
PA chime" above is a description of the note table, not an ear-verified claim.

**`"beep"` (added 2026-09-19)** is a single ~60ms blip, deliberately smaller
than every other tune — see `include/jingle.h`'s `kBeep`. It's the API's
presentation for `kind: "sensor.reading"` (`services/api/src/triage.ts`),
alongside a green (`#00ff00`) LED: today only `services/feeds/ha-temperature`
sends that kind, so in practice this plays for every room-temperature update
that changed enough to report. That kind used to be fully silent and dark
(`QUIET`) — changed because indistinguishable-from-off wasn't actually
useful feedback that a reading came in. Getting this to fire at all also
needed `presentationFor()`'s `low`-priority handling changed: it used to
unconditionally strip the jingle off any `low`-priority message (the feed
always sends `sensor.reading` at `low`), which would have silenced this
right back — see the comment above that function for why the blanket strip
was removed instead of special-cased.

**Verified live 2026-09-19** on the same board (`Ziggy`, `10.0.0.114`), same
method as the 2026-09-17/18 tables: publish to `avatar/say`, read the serial
log, negative control included.

| Published | Serial output |
| --- | --- |
| `{"led":"#00ff00","jingle":"beep",...}` | silent — parsed, tune plays |
| `{"led":"#00ff00","jingle":"boop",...}` | warned and fell back, same as before |

Same caveat as the other tables: this confirms parsing, not what the beep
sounds like or whether the LED actually reads as green through the
unmatched-resistor tint mentioned above — nobody looked at or listened to
the board for this check.

Config lives in `include/secrets.h` (gitignored — copy `secrets.h.example`
and fill in `WIFI_SSID`/`WIFI_PASS`/`MQTT_HOST`/`MQTT_PORT`/`MQTT_TOPIC`).

A few sharp edges worth knowing if this stops working:

- **PubSubClient's default 256-byte buffer silently drops anything larger** —
  no error, nothing in the callback, the message just never arrives.
  `mqtt_link.h` calls `setBufferSize(512)` explicitly; if messages start
  disappearing, check payload size against that first.
- **Keepalive is bumped to 60s** (`setKeepAlive(60)`, default is 15s) because
  `bubble->show()` blocks per-character for `strlen * charDelayMs` — a long
  message can eat several seconds inside the callback, during which
  `client.loop()` isn't being re-entered.
- **`appTask`'s stack is 8192 bytes**, not the demo's old 4096 — WiFi,
  PubSubClient and ArduinoJson buffers all share it now, and the old size
  overflows silently once networking is in the mix.
- **Reconnect checks WiFi before retrying MQTT**, not two independent retry
  loops — the common hobby-AP failure mode is WiFi dropping mid-MQTT-retry
  and hammering `client.connect()` against a dead link.
- The board publishes `avatar/status` (`"online"`/`"offline"` via MQTT LWT,
  retained) so anything watching can tell if it's actually up.
- **`MqttLink::showStartupInfo()`'s bubble message** reports MQTT
  host/port/status, the device name (`deviceName_`, doubling as the WiFi
  hostname — set via `WiFi.setHostname()` in `connectWiFi()`, ahead of
  `WiFi.begin()`, since ESP32 only honors it if set before the connection is
  made) + IP, and the BLE device name/address.
  **Correction, 2026-09-16:** this used to show automatically, once, right
  after `appTask` connects — added 2026-09-15 so that was readable off the
  panel without a laptop. Changed so it no longer appears on boot at all: a
  freshly-flashed device sitting on a desk has no reason to broadcast its
  diagnostics before anyone's asked for them. It now only shows on demand —
  a click on the button while the bubble is idle **and no MQTT/BLE message
  has ever arrived yet** (see `MqttLink::onButtonClick()`'s
  `configInfoRequested_` branch, deferred to `loop()` the same way a replay
  is). Once any message has been shown, that latches for good and the same
  idle click instead replays the last message — this diagnostic screen is
  unreachable again until the next reboot. `main.cpp`'s `appTask` still
  starts `bleConfig.begin()` ahead of this, but now only so
  `mqttLink.setBleIdentity()` can capture the BLE address
  (`NimBLEDevice::getAddress()`) for whenever the button click does arrive.
- **The "ISS is passing overhead" message some sessions saw isn't from this
  repo at all** — it's `~/Homelab/osmo/avatar-brain`'s `producers/iss.py`, a
  separate MQTT publisher that polls a live-position API and posts to
  `avatar/say` when the ISS is within 500km, in a project this board just
  happens to subscribe to. Disabled 2026-09-15 in that repo's `main.py`
  (`IssPasses()` dropped from `PRODUCERS`) at Kevin's request — the producer
  file itself is left in place there in case it's wanted back.
- **Corrected 2026-09-17:** this used to say flash was at **88% of the 1.25MB
  app partition**, with "not a lot of headroom left for more libraries". That
  was measured before `partitions_huge_app.csv` took effect (see the comment in
  `platformio.ini`), which trades the second OTA slot for a 3MB app partition.
  Measured today on the contract v2 build: **1,439,611 bytes, 45.8% of
  3,145,728**. The old number was believable because it was true of the old
  partition table — but the conclusion drawn from it, that there was no room to
  grow, is no longer the case.
- **The device has an affectionate "device name"** (`DeviceSettings::name`,
  default `mqttchan`, editable from the control page's Settings panel — see
  `docs/index.html`), not just a secrets.h-configured hostname. It's used as
  the WiFi hostname, the BLE beacon name/GAP name, and the self-reference
  text in `showStartupInfo()` above. WiFi hostname changes take effect on the
  next reconnect, same as any other BLE-written setting (`reconfigure()`
  forces one). The BLE name is different: `BleConfigService::renameDevice()`
  re-advertises under the new name live, without a reboot — `NimBLEDevice::
setDeviceName()` plus `NimBLEAdvertising::setName()` + a stop/start cycle,
  called from `onConfig_`'s own NimBLE host-task thread since (unlike
  WiFi/MQTT) none of that touches lwIP.
- **The bubble panel no longer goes blank while booting.** `appTask` types
  "Connecting to `<ssid>`" on the bubble right before the blocking
  WiFi connect, then "Fetching" once that attempt has settled and
  MQTT/SNTP take over. `DigitalClock::draw()`'s unsynced branch (in
  `digital_clock.h`) picks up that same "Fetching" text once
  `idleClock` starts ticking, so the panel stays on message instead of
  blanking for however long SNTP/MQTT actually take. **Correction,
  2026-09-16:** an earlier version of this file said the
  unsynced clock panel should stay blank because the startup jingle already
  covers the wait — that only holds for the jingle's few seconds, not for a
  slow broker or NTP server, so the blank fallback is gone.

**Headless bench test, no broker needed:** build with `-DAVATAR_FB_DUMP` and
`appTask` injects one synthetic payload straight into the parse-and-display
path (`MqttLink::injectForTest()`) before entering its normal loop, then
dumps both panels' framebuffers to serial — exercises the whole JSON →
expression → display pipeline without a live MQTT broker. See "Seeing what
the panel shows" below for the flag mechanics.

**Corrected 2026-09-17 — this section used to describe a limitation that no
longer exists.** It said `SpeechBubble::wrapLines()` doesn't cap vertical line
count, so "text too long for the 64px panel just wraps past the bottom edge and
isn't visible", and concluded that publishers should keep messages well under
~50 characters. That was true when written, and stayed believable because the
50-character advice is good for _readability_ either way.

What actually happens now: `show()` sets a scroll rect over the content area and
calls `scroll(0, -lineHeight)` once lines exceed `maxLines`, so long text scrolls
up a row at a time as it types rather than disappearing off the bottom. Nothing
is lost to the panel edge.

The real costs of long text are different, and both are timing:

- It reveals at ~45ms/char, so a 200-character message takes ~9s to type, during
  which `mqtt_.loop()` is not being serviced.
- Lines that have scrolled off cannot be re-read — the message has to be read as
  it types.

The only hard limit is the **512-byte payload cap** below, which is about the
whole JSON payload rather than the text. Pacing long messages is `services/api`'s
job (see its queue, which derives the gap between publishes from text length),
not something this file needs to police.

## Where to hook the "TBD" half

`speakFor()` (demo mode only) drives `mouthOpenRatio` from random noise as a
placeholder lip-sync. A real TTS or mic-amplitude source would need its own
hook in MQTT mode, since the MQTT callback currently only calls
`setExpression()`/`bubble->show()` — nothing drives the mouth outside demo
mode yet. No speaker is wired to this board either way, and
`cfg.internal_spk` is off in `setup()` — turn it on when an I2S DAC is added.
The library also ships `tasks/LipSync.h` for mic-driven mouth movement, which
is unused here.

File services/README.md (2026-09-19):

# services

TypeScript. Two kinds of thing live here: **the API**, which is the only process
that speaks MQTT, and **feeds**, which poll something and POST what they found.

```
packages/contract   the feed <-> API interface (shared types + JSON schema)
packages/feed-kit   the client, poll loop and change tracking every feed needs
api                 triage, rate limiting, and the MQTT connection
feeds/example       a template feed, not a real integration
feeds/flights       arrivals and departures at ZQN, from live ADS-B
feeds/ha-temperature  room temperatures from Home Assistant, Zigbee sensors only
feeds/sky           sun/moon/planet digest, aurora Kp alert, MetService warnings
```

## The idea

A feed says *what happened*. The API decides *how it looks* and *when it shows*.

A feed never picks a color or a jingle, and never opens an MQTT connection.
It sends:

```json
{ "source": "ha-temperature", "kind": "sensor.reading",
  "text": "Office 20.1C", "priority": "low",
  "dedupeKey": "sensor.office", "ttlSeconds": 900 }
```

...and gets back `{"decision":"queued"}`, `"deduped"` or `"dropped"` with a
reason. That response is worth reading: a feed that is being rate limited should
know.

## What the API does with it

1. **Rate limit per source** — a token bucket, so one noisy feed cannot
   monopolise the device.
2. **Triage** (`src/triage.ts`) — `kind` + `priority` decide LED color,
   blink and jingle. This is the one place presentation is decided, which
   is what keeps the device's voice consistent and lets the MQTT contract change
   without touching a feed.
3. **Dedupe** — a newer message with the same `dedupeKey` *replaces* the queued
   older one. For sensor feeds this is the rule that does the real work: you see
   the current reading, not a backlog of its history.
4. **Pace** — the gap before the next publish is derived from the message, not a
   flat constant: `jingle + text.length * 45ms + 30s hold`. A long message
   legitimately needs longer, because the bubble types it out one character at a
   time.
5. **Expire** — anything that has waited longer than its `ttlSeconds` is dropped
   rather than shown stale.
6. **Order** — `high` overtakes `normal` overtakes `low`; FIFO within a priority.

`GET /v1/status` reports queue depth, per-source counters and the dedupe/drop
counts. That is how you find out whether the tuning is right: lots of drops means
a feed is too chatty, an idle device means its threshold is too high.

## Writing a feed

Copy `feeds/example`. It is deliberately small — `feed-kit` already provides the
API client with retries, a poll loop that survives a throwing tick, and
`ChangeTracker` for edge-triggered reporting.

**Use `ChangeTracker`.** The Python service this replaces had a producer that
announced the ISS overhead on *every* poll while it was still overhead, and it
got switched off for being noisy. `changedBy(key, value, threshold)` reports on
the first reading and then only when the value has moved enough to be worth
saying, measuring drift from the last *reported* value rather than the last seen
one.

Every feed should support `--once --dry-run`, which polls the real source and
prints what it would send without connecting to anything. It is the fastest way
to check a new feed's output.

## Running

```
npm install
npm run build
npm test

MQTT_HOST=osmo node api/dist/index.js
API_URL=http://localhost:8420 node feeds/example/dist/index.js --once --dry-run
```

## Deploy

One image for the whole workspace — the API and every feed share dependencies
and a build step, so compose picks which to run with `command`. Unlike the rest
of this homelab (a directory per service, published to a host port, addressed by
osmo's LAN IP), these share a compose network: they are one stack, and a feed has
no reason to be reachable from outside it. Only the API publishes a port, and
only for debugging.

```
scp -r . kevin@osmo:~/mqttchan-services
ssh kevin@osmo 'cd ~/mqttchan-services && docker compose up -d --build'
```

Copy `.env.example` to `.env` on the host and `chmod 600` it.

## The ZQN flights feed

`feeds/flights` announces arrivals and departures at Queenstown from live
ADS-B. Built and verified against a real landing on 2026-09-18; see
[`feeds/flights/README.md`](feeds/flights/README.md) for how a movement is
detected, the four rules that stop false positives, and two undocumented
adsb.lol behaviours that will otherwise cost you an hour.

## The Home Assistant temperature feed

**Changed 2026-09-18 (later the same day):** this section used to be "Still to
do", holding only research. `feeds/ha-temperature` is now built — see
[`feeds/ha-temperature/README.md`](feeds/ha-temperature/README.md). The
research below from 2026-09-17 still stands and fed directly into it; nothing
in it was wrong.

Verified against live HA on 2026-09-17, so it doesn't need rediscovering:

- HA exposes **12 entities with `device_class: temperature`**, all °C. Eight are
  useful room sensors — Office, Dining Area, Bedroom, Shed, Laundry, Network
  Cabinet, Bathroom, plus `sensor.home_temperature`.
- **Exclude `sensor.system_monitor_processor_temperature`** — it changes every
  ~45s and is CPU temperature, not a room.
- **Two sensors read `unavailable`** (Kitchen Pantry, Living Room) — the known
  BTHome casualty of osmo's `hci0` Bluetooth crash loop. Treat
  `unavailable`/`unknown` as "no reading", never as a change worth announcing.
  Zigbee end-devices also read that way for up to an hour after an HA restart.
- Cadence is roughly one change every 1–3 minutes across the set — bursty, and
  near the device's ceiling. Dedupe by entity id and a ~0.5°C threshold.
- `Office 20.1°C` is 13 characters, so text length is not a concern here.

The long-lived token goes in `.env` on osmo. The one still sitting in the old
`avatar-brain/.env` returns 401, which is why that service never published
anything.

## The Queenstown sky feed

`feeds/sky` announces a once-daily sun/moon/planet-and-weather digest, an
edge-triggered aurora alert from NOAA's planetary Kp index, and MetService
severe weather watches/warnings for Queenstown - see
[`feeds/sky/README.md`](feeds/sky/README.md). Only the weather outlook needs
an API key (`METSERVICE_API_KEY`, MetService's Point Forecast API); confirmed
live 2026-09-19 for Queenstown's coordinates. Everything else in the feed
needs none.

**Resolved 2026-09-18:** this research didn't establish which HA integration
those Zigbee sensors run on (ZHA, Zigbee2MQTT, deCONZ). `HA_ZIGBEE_INTEGRATION`
defaults to `zha`, and running the feed against live HA on osmo confirmed that
guess was right first try - 7 sensors, matching seven of the eight room names
above (`sensor.home_temperature` turned out not to be a `zha` entity - see
`feeds/ha-temperature/README.md`'s Verified section for why). Both BTHome
sensors and the CPU monitor were correctly excluded despite sharing
`device_class: temperature`.

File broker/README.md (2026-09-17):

# mosquitto

MQTT broker for the mqttchan pipeline: `services/api` publishes to
`avatar/say`, the ESP32 in `firmware/` subscribes. Anonymous auth, no TLS —
acceptable only because this is reachable exclusively over LAN/Tailscale,
never the public internet.

**Moved here 2026-09-17** from `~/Homelab/osmo/mosquitto`, unchanged, when the
firmware, broker and services were collapsed into this monorepo. The Homelab
copy is now a stub pointing here.

## Deploy

This directory is a reference copy — osmo's runtime config is authoritative.
Deploy by copying it there and bringing it up with `docker compose`, not raw
`docker`, matching the rest of this homelab:

```
scp -r broker kevin@osmo:~/mosquitto
ssh kevin@osmo 'cd ~/mosquitto && docker compose up -d'
```

Verified 2026-09-17: the running container on osmo is byte-identical to the
files here, so this copy is current rather than drifted.

## Ports

- **1883** (raw MQTT/TCP) — what the ESP32 and `services/api` actually use.
  Connect via osmo's LAN (`10.0.0.5`) or Tailscale IP directly; not fronted
  by Caddy since it isn't HTTP.
- **9001** (MQTT-over-WebSockets) — for browser tools/future dashboards.
  Add this to osmo's live Caddyfile (not tracked here) to get a TLS +
  hostname endpoint:

  ```
  mqtt.kev.nz {
      reverse_proxy localhost:9001
  }
  ```

  The control page (`docs/index.html`) is the one thing that needs 9001: it
  runs in a browser, which cannot open a raw MQTT socket.

  Only 9001 goes through Caddy. Devices that speak plain MQTT should use
  1883 directly — no reason to pay for WebSocket framing on a
  memory-constrained device like the ESP32.

## Security note

Anonymous auth on both listeners. Fine under LAN/Tailscale-only access;
would need a password file (`mosquitto_passwd`) and `allow_anonymous false`
before this could ever be exposed further.

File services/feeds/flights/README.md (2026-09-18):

# feeds/flights

Announces arrivals and departures at one airport, from live ADS-B. Configured
for **ZQN** (Queenstown, NZQN); the airport is three environment variables, so
pointing it elsewhere needs no code change.

```
node feeds/flights/dist/index.js --once --dry-run
```

## How a movement is detected

There is no arrivals/departures API in play — only where every aircraft is
right now — so a movement is an **edge**: the same airframe seen on the ground
at the field after being airborne, or the reverse. `src/movements.ts` is the
whole of it, and is pure so it can be tested without the network.

Four rules stop that edge firing when nothing happened. Each one is a real
false positive that was observed, not a hypothetical:

- **Ignore non-transponder contacts (`type` ending `_nt`).** NZQN's 30nm circle
  holds six of them, two self-identifying as `TWR`. They are ADS-B ground
  infrastructure, they sit permanently at `alt_baro: "ground"`, and without
  this they look exactly like aircraft parked at the airport.
- **A first sighting is silent.** It records where the aircraft is and says
  nothing, because there is no way to tell a fresh arrival from something that
  has been on the apron for an hour. Without this, every start of the feed
  announces the whole apron as arriving at once.
- **"On the ground" means within 1.5nm of the reference point.** Cromwell is
  ~25nm away, inside the watch circle. An aircraft on the ground anywhere else
  is *ignored* rather than tracked, which deliberately leaves its remembered
  airborne state intact — so if it later comes here, the arrival still fires.
- **Ten-minute cooldown per airframe per movement.** A circuit or a go-around
  produces genuine ground/air edges that nobody wants told twice.

Forgetting an aircraft after 45 minutes unseen can only ever cost a missed
announcement, never invent one: a forgotten aircraft is re-baselined in
silence. That asymmetry is what makes the expiry safe.

The ground/air state comes from `alt_baro == "ground"`, which is the aircraft's
own air/ground status bit (weight-on-wheels), not a guess derived from
altitude — so no field-elevation threshold is needed or wanted.

## Notes on the source (adsb.lol)

Both of these cost an hour on 2026-09-18 and neither is documented anywhere
obvious:

- **A generic User-Agent is rejected** — `403 "User-Agent too generic; include
  valid contact info."` Node's default UA trips it; curl's does not, which is
  why a curl spike succeeds and the obvious `fetch()` port of it fails with
  what looks like an unrelated error.
- **`fetch()` cannot be used.** api.adsb.lol publishes AAAA records whose
  addresses blackhole from this network (`curl -6` never connects, `curl -4`
  returns 200), and `fetch()` hangs until `ETIMEDOUT` with no way to say "IPv4
  only" — `dns.setDefaultResultOrder("ipv4first")` does not help and undici's
  happy-eyeballs fallback does not rescue it. `node:https` takes `family: 4`
  natively, so `src/adsb.ts` uses it. Set `ADSB_IP_FAMILY=0` to hand the choice
  back to the OS somewhere with working IPv6 to them.

Chosen over a local SDR because that was already the recorded decision: the
predecessor service's README named "airplanes.live or adsb.lol keyed to
lat/lon + radius, not local SDR hardware". airplanes.live serves the same
`/v2/point` shape and is the fallback if this goes away.

## Naming the route (adsbdb.com)

adsb.lol only ever gives a position, never where a flight came from or is
going — so once a movement is detected, `src/routes.ts` makes a second,
unrelated lookup to `api.adsb.lol`'s namesake-but-separate `adsbdb.com`,
keyed on the callsign alone, and the message becomes e.g.
`QFA122 left ZQN for SYDNEY` instead of `QFA122 left ZQN`.

This is decoration, never a gate: `fetchRoute` swallows every failure —
unfiled callsign, network error, timeout — and returns `null`, and
`movementText` falls back to the plain form. A movement is never held back or
dropped for want of a route.

Verified live 2026-09-18:

- `GET /v0/callsign/ANZ611` → Auckland → Queenstown; `GET
  /v0/callsign/QFA122` → Queenstown → Sydney. The route sits at
  `response.flightroute.{origin,destination}.municipality` — nested one level
  deeper than it looks at a glance, and the first version of this lookup
  missed the `flightroute` wrapper and silently returned `null` for every
  callsign until a live check against ANZ611 caught it.
- A registration (`ZK-OYB`) comes back `400 invalid callsign`, an unfiled or
  made-up callsign (`NOTREAL1`) comes back `404 unknown callsign` — both as
  `{"response": "<message>"}`, not a thrown error, so `fetchRoute` reads that
  shape as "no route" rather than a failure.
- **The same IPv6 blackhole as api.adsb.lol hits this host too**: node's
  `fetch()` hangs to `ETIMEDOUT` against `api.adsbdb.com`, `https.get` with
  `family: 4` returns 200 immediately. `routes.ts` forces IPv4 the same way
  `adsb.ts` does, for the same reason.
- The hex and registration fallbacks `identify()` produces when no callsign
  was transmitted are skipped before the request is even made — adsbdb has no
  route for either, and a bare hex (e.g. `C829AC`) otherwise looks enough like
  a valid callsign shape to be worth guarding against explicitly.

## Verified

2026-09-18, against the live API and a real movement:

- A 30nm point query on NZQN returns real traffic, and `--once --dry-run`
  classifies it correctly: 6 contacts, 5 of them ground infrastructure marked
  `ignored`, ANZ611 (ZK-OYB, A21N) marked `ground` at 0.0nm.
- **A complete real arrival was captured and replayed through the detector.**
  15 snapshots at 31s intervals, ANZ611 descending 5550ft at 11.8nm through to
  `ground` at 0.27nm and taxiing in at 3kt. The detector announced
  `ANZ611 landed at ZQN` exactly once, on the first ground snapshot — and
  stayed silent for the 9 airborne snapshots before it and the 5 ground
  snapshots after.
- Against a locally running API: two distinct movements `queued`, and a repeat
  of the same airframe's same movement `deduped`. `kind: "notice"` is accepted
  by triage as-is.

**Departure confirmed live 2026-09-18**, 09:20 NZST: `ZKICH left ZQN`,
published from the deployed container within twenty minutes of the stack coming
up. `flights` recorded submitted 1 / queued 1 / published 1 — no duplicate from
the aircraft's subsequent climb snapshots, nothing dropped, queue drained. This
replaces an earlier note here saying a departure had only unit tests behind it;
it was accurate when written and is now superseded.

Still unobserved in production: the cooldown and the 45-minute expiry actually
firing, since neither has had a circuit or a coverage dropout to act on yet.

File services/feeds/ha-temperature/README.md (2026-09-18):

# feeds/ha-temperature

Reports room temperatures from Home Assistant - Zigbee sensors only.

```
node feeds/ha-temperature/dist/index.js --once --dry-run
```

## Why "Zigbee only" needs asking, not guessing

`GET /api/states` gives every entity's `device_class`, and `temperature` looks
the same regardless of radio. This HA instance also has BTHome (Bluetooth)
sensors with `device_class: temperature` - two of them, Kitchen Pantry and
Living Room, are recorded in `services/README.md` as the known casualty of
osmo's `hci0` Bluetooth crash loop. Nothing in an entity's id, its name or its
state distinguishes a Zigbee reading from a Bluetooth one; only HA's own
integration membership does.

So this feed asks HA directly, via `/api/template` and its `integration_entities()`
Jinja function (`src/ha.ts`), for the entity ids that belong to one configured
integration (`HA_ZIGBEE_INTEGRATION`), and only reports a `device_class:
temperature` entity that also appears in that set. `src/temperature.ts` is the
whole of that rule, kept pure and tested without a live HA to talk to, same
reasoning as `flights/src/movements.ts`.

**`HA_ZIGBEE_INTEGRATION` defaults to `zha`, and that default is unverified.**
HA's built-in ZHA integration is the common case for a setup with no separate
MQTT bridge, but nothing in this repo or in the old `avatar-brain` producer it
replaces says which integration osmo's HA actually runs - Zigbee2MQTT and
deCONZ are both real possibilities and would need a different value here. A
wrong guess is safe, not silent-wrong: it shows up as `--once --dry-run`
printing zero sensors, not as a Bluetooth reading mislabelled as Zigbee, because
the two checks (`device_class` and integration membership) are independent and
both have to pass.

## Why report-on-change rather than an edge detector

Unlike `feeds/flights`, this is exactly the case `feed-kit`'s `ChangeTracker`
was built for: HA has already done the sensing, so there is no arrival/departure
style edge to detect - just a value that should be reported once and then only
again once it has moved. `services/README.md` names the previous Python
service's failure mode this avoids: a producer that re-announced its reading on
every poll while nothing had changed.

## Notes on the source (Home Assistant's REST API)

- **`/api/states` has no integration field.** `device_class`, `friendly_name`
  and `unit_of_measurement` are on every state, but which integration owns an
  entity is not - that's what makes `/api/template` + `integration_entities()`
  necessary rather than an incidental choice.
- **`/api/template` returns rendered text, not JSON**, even though the request
  body is JSON. `src/ha.ts` renders the template with a trailing `| tojson`
  filter and parses the response as text for exactly this reason - reading it
  with `res.json()` would fail.
- **`unavailable`/`unknown` is not a reading.** `services/README.md` records
  that Zigbee end-devices sit in that state for up to an hour after an HA
  restart, same as the two BTHome sensors after osmo's Bluetooth crashes.
  `readingsOf` in `src/temperature.ts` skips both states outright rather than
  parsing them as numbers or reporting a change away from "nothing".
- **Same env var names as the predecessor.** `avatar-brain/producers/ha_sensors.py`
  established `HA_URL` and `HA_TOKEN` (a long-lived access token from HA's own
  profile page); this feed keeps them rather than inventing new ones. That
  service's own token in `avatar-brain/.env` on osmo returns 401 - it needs a
  fresh one in `mqttchan-services`' `.env`, not a copy of the old one.

## Verified

**2026-09-18, against live HA on osmo.** `HA_ZIGBEE_INTEGRATION=zha` was a
guess when this was written, and it turned out to be right on the first try:
`--once --dry-run` against the real `HA_URL`/`HA_TOKEN` returned exactly 7
sensors -

```
Office           16.9°C  (sensor.lumi_lumi_weather_temperature)
Dining Area      19.4°C  (sensor.lumi_lumi_weather_temperature_2)
Bedroom          17.3°C  (sensor.lumi_lumi_weather_temperature_3)
Shed             12.0°C  (sensor.lumi_lumi_weather_temperature_4)
Laundry          16.1°C  (sensor.lumi_lumi_weather_temperature_5)
Network Cabinet  20.4°C  (sensor.lumi_lumi_weather_temperature_6)
Bathroom         17.5°C  (sensor.lumi_lumi_weather_temperature_7)
```

- Both BTHome sensors (Kitchen Pantry, Living Room) and the CPU monitor are
  correctly absent - `zha` membership excludes them even though the CPU one
  shares `device_class: temperature`.
- **`sensor.home_temperature`, one of the "eight useful room sensors" named in
  `services/README.md`'s original research, is also absent** - it does not
  belong to the `zha` integration. It reads as a virtual/aggregate entity
  (there is no matching `_2`/`_3` suffix pattern like the seven Lumi/Aqara
  devices above, which is what a template or group sensor built from other
  readings would look like), not a physical Zigbee radio, so this feed
  correctly leaves it out under a "Zigbee sensors only" brief - even though
  the original research counted it among the sensors worth reporting.
- All 7 readings were sent through the real API and `docker logs` confirmed
  `queued` for every one; the deployed container is running continuously via
  `docker-compose.yml`, no profile gate needed any more.
- Unit tests in `test/temperature.test.ts` cover the filtering and naming
  logic against fixtures shaped like HA's state format; the numbers above are
  the first live confirmation that the fixtures weren't hiding anything.

Still unconfirmed: `ChangeTracker`'s 0.5°C threshold and 900s TTL haven't seen
a real day's worth of drift yet, so whether the cadence is right is not yet
known.

**Correction, 2026-09-18 (same day):** the message text this feed sends is
plain ASCII - `Office 20.1C`, no degree sign - not `20.1°C` as the readings
above and the original research in `services/README.md` show it. On the real
device the degree sign rendered as two garbage glyphs, because
`SpeechBubble::show()` (`firmware/include/speech_bubble.h`) types a message
out one raw *byte* at a time, and `°`'s UTF-8 encoding is two bytes (`0xC2
0xB0`) - splitting them apart means neither byte reaches the font as the
character it was meant to be. `src/index.ts`'s `formatReading()` is the fix,
and it is the one place in this feed that still matters for what actually
shows on screen; the numbers logged elsewhere in this README (from `--once
--dry-run`, before this was caught) keep the degree sign because that output
is a terminal, not the device, and terminals render UTF-8 fine.

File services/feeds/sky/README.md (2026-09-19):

# feeds/sky

Announces sun, moon and visible-planet events, aurora-relevant space
weather, and MetService severe weather watches/warnings for one location.
Configured for **Queenstown, Otago** by default; the location is five
environment variables, so pointing it elsewhere needs no code change.

```
node feeds/sky/dist/index.js --once --dry-run
```

## What's in v1

- **Sun/moon/planet digest, once a day.** `src/astro.ts` wraps
  [`astronomy-engine`](https://github.com/cosinekitty/astronomy), a
  deterministic offline ephemeris - no network call, no key, same inputs
  always give the same outputs. It computes sunrise/sunset, moonrise/moonset,
  the moon's phase name and illumination percentage, and which naked-eye
  planets (Mercury, Venus, Mars, Jupiter, Saturn) clear 5 degrees of altitude
  at dusk or the following dawn. The digest fires once per calendar day (in
  `LOCATION_TIMEZONE`), not on every poll.
- **Today's weather outlook, in the same digest.** `src/weather.ts` calls
  MetService's Point Forecast API (`forecast-v2.metoceanapi.com`) for high/low
  temperature, cloud cover, expected rainfall and wind - the one part of this
  feed that needs `METSERVICE_API_KEY`. With no key set, the digest is sent
  without this clause rather than not sent at all - see below.
- **Aurora alert from NOAA's planetary Kp index.** `src/spaceweather.ts`
  polls `services.swpc.noaa.gov/products/noaa-planetary-k-index.json`, public
  and keyless. This is the practical form "sun activity" takes for a
  Queenstown latitude: geomagnetic activity, not solar X-ray flux, is what
  actually gates whether the aurora is worth a look from here. Kp 5 (G1
  minor storm) is the default alert threshold - edge-triggered (fires once as
  Kp crosses up through it, not on every poll while it stays elevated) with
  hysteresis against a reading bouncing across the line.
- **MetService severe weather watches/warnings.** `src/warnings.ts` reads
  MetService's public CAP Atom feed at `alerts.metservice.com/cap/atom` - no
  key, no registration.

Everything except the weather outlook needs no API key at all.

## Wiring up the weather outlook (`METSERVICE_API_KEY`)

Researched 2026-09-19: MetService's current docs site
(`developer.metservice.com`) describes the Point Forecast API's existence
(REST, OpenAPI 3.0, x-api-key auth) but does not publish the endpoint path,
request shape or variable names anywhere reachable without a console
account. The real shape came from MetOcean's own examples repo instead -
[`metoceanapi/forecast-api-examples`](https://github.com/metoceanapi/forecast-api-examples) -
and was then confirmed live against a real key and Queenstown's coordinates:

- `POST https://forecast-v2.metoceanapi.com/point/time`, header
  `x-api-key: <key>`, body
  `{points: [{lon, lat}], variables: [...], time: {from, interval, repeat}}`.
- The variable catalogue is itself an endpoint -
  `GET https://forecast-v2.metoceanapi.com/variables/` - rather than a fixed
  list to keep in sync by hand. This feed requests six:
  `air.temperature.at-2m` (Kelvin), `precipitation.rate` (mm/hour),
  `wind.speed.at-10m`, `wind.speed.gust.at-10m` (both meters/second),
  `wind.direction.at-10m` (degrees, meteorological "from" convention) and
  `cloud.cover` (percent).
- The response is `{dimensions, noDataReasons, variables}`, where each
  requested variable comes back as `{data: number[], noData: number[]}` -
  one entry per requested time step. `noData` is `0` for a good sample and a
  `noDataReasons` code otherwise (e.g. a wave variable requested over land
  comes back `MASK_LAND`); `weather.ts` drops any sample whose `noData` isn't
  `0` rather than trusting a bogus number.
- Sample response for Queenstown's coordinates, 2026-09-19: 5 time steps
  (3-hourly) gave `air.temperature.at-2m` of 279.7K down to 274.5K (6.6C down
  to 1.4C - a realistic September night), `wind.speed.gust.at-10m` up to
  17.9 m/s (64km/h), matching a live Crown Range Road snow warning seen the
  same day.

`fetchDailyOutlook` requests 8 steps at a 3-hour cadence (roughly the next
24h) and reduces them to a daily high/low, a rough total-rainfall estimate
(each sample's mm/hour rate times the 3-hour interval, summed - a real
integral this is not, but close enough for "rain expected today: roughly
Xmm"), the windiest step's speed/gust/direction, and mean cloud cover
bucketed into clear/partly cloudy/overcast.

Also plausible, not built: solar flare class (X-ray flux) as a second space
weather signal alongside Kp; supermoon/perigee note on the moon phase;
sidereal notes (equinox/solstice countdown). None of these needed a decision
to leave out - they just aren't "the basics" yet.

## Region matching for warnings

MetService's Atom feed lists every current watch/warning nationwide with no
region field on the entry itself - only the linked CAP XML document (one
extra HTTP request per entry) carries an `areaDesc`. `matchesRegion` checks
that description, case-insensitively, against `SKY_REGION_KEYWORDS`
(default: Otago, Queenstown, Southern Lakes, Wakatipu, Wanaka, Crown Range,
Cardrona, Coronet Peak, Remarkables, Fiordland).

**Verified live 2026-09-19** against the real feed: a "Strong Wind Watch"
entry's `areaDesc` read "Hawke's Bay south of Waipawa and the Tararua
District" - nowhere near Otago, and nothing in its title or id would have
told you that. A same-day "Road Snowfall Warning" entry's *id* already named
`crownrangeroad`, but that is not something to rely on - the general "Strong
Wind Watch" entries use a generic `severeweather.nz` id with no location
hint at all, so opening the CAP document is the only reliable way to check.

## Escalation: Watch vs Warning

MetService's own ladder is Watch (possible) below Warning (expected).
`isWarningLevel` reads that straight off the headline text ("Warning" vs
anything else, e.g. "Watch" or "Advisory"). A Warning sends `kind: "alert"`
at `priority: "high"` (the device's only blinking kind); a Watch sends
`kind: "notice"` at `priority: "normal"` (the same boarding-style chime
`feeds/flights` uses) - worth knowing about, not worth the alarm.

## Verified

2026-09-19, against the real astronomy-engine library (offline, deterministic)
for Queenstown's coordinates: sunrise/sunset, moonrise/moonset, moon phase
angle and illumination, and dusk/dawn planet altitudes all reproduced exactly
against a fixed reference time in `test/astro.test.ts` - see that file for
the reference values.

2026-09-19, against the live services:

- `services.swpc.noaa.gov/products/noaa-planetary-k-index.json` returns a
  JSON array of `{time_tag, Kp, a_running, station_count}` objects, oldest
  first, no header row.
- `alerts.metservice.com/cap/atom` returns a real Atom feed of current
  watches/warnings (a Strong Wind Watch and two Road Snowfall Warnings seen
  live); each entry's `link[rel=related]` points at a CAP 1.2 XML document
  with `info.headline`, `info.description`, `info.severity` and
  `info.area.areaDesc`.

2026-09-19, against the live Point Forecast API with a real key: a
`point/time` request for Queenstown's coordinates returned real, physically
sane data (see above), and `--once --dry-run` produced a full digest
including the weather clause, e.g. "high 7C, low 1C, overcast. 8mm rain
expected. WSW wind to 15km/h, gusts 65km/h." - consistent with the
Crown Range Road snow warning active the same day.

Not yet observed in production: an actual aurora alert firing (Kp has not
reached 5 since this was built). Exercised by unit tests against real
captured data, not yet by a live event.

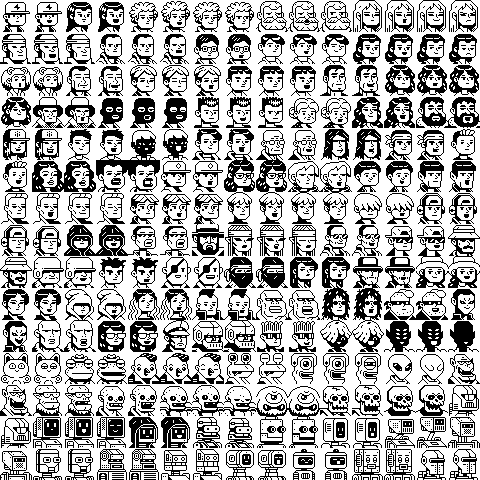
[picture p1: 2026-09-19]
assets/1-bit dialogue portraits/sprite sheet.png

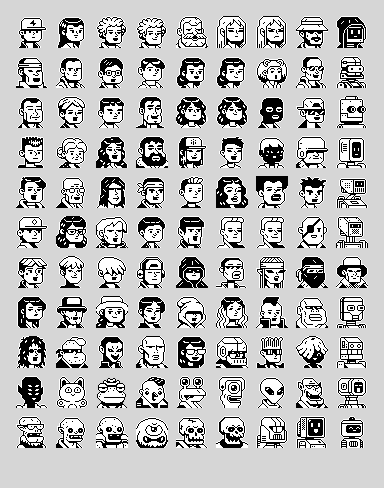
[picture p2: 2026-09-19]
assets/1-bit dialogue portraits/prewiev.gif

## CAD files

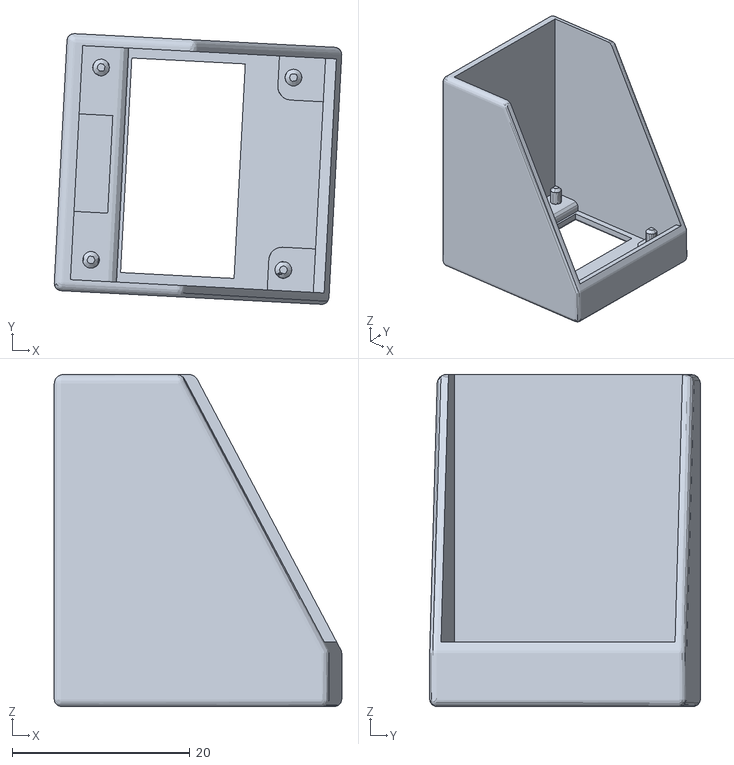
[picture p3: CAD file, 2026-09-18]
case/source/single oled case.stl
32.4 x 30.5 x 37.4

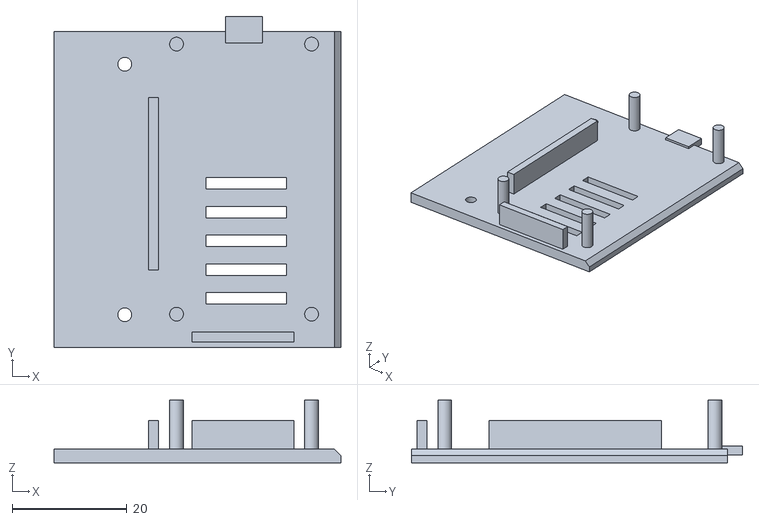
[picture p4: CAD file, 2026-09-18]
case/source/zqn_case_lid.stl
49.9 x 57.6 x 10.9

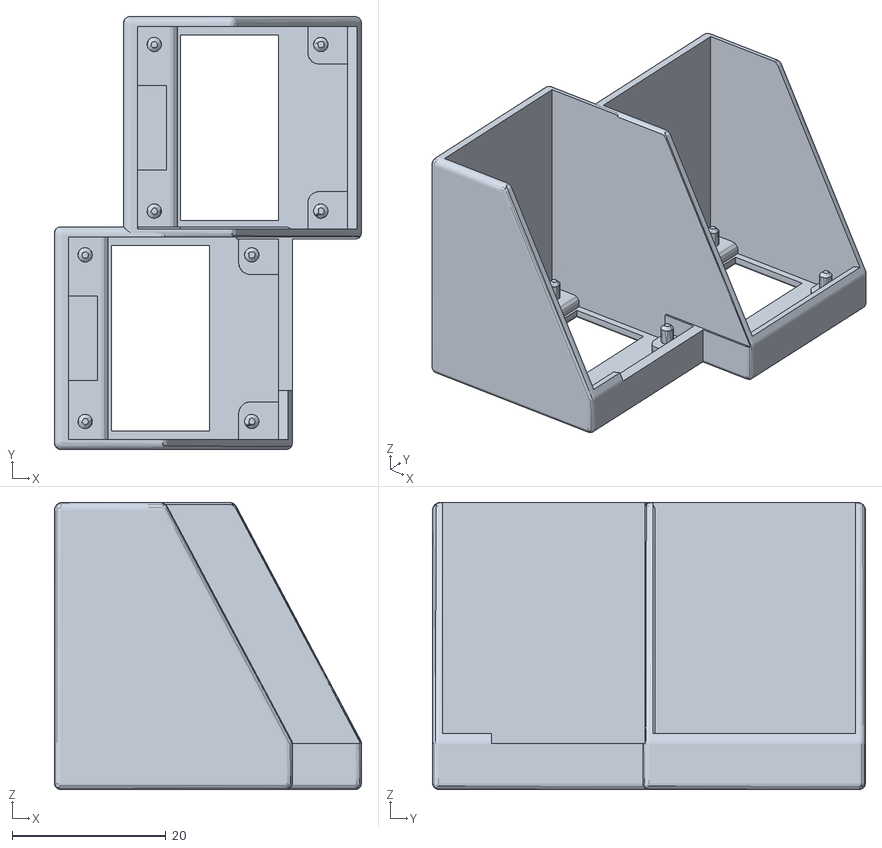
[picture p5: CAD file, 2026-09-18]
case/source/double oled case.stl
40.0 x 56.4 x 37.4

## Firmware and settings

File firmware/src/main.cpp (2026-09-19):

// Bare ESP32-WROOM + two SSD1306 128x64 OLEDs: one for the announcer's face
// (a random portrait, see portrait_face.h), one for the typed message.
//
// Correction, 2026-09-18: this used to run m5stack-avatar's procedural
// eyes/mouth on the face panel, which is why this file's core split existed
// - m5stack-avatar hardcodes both of its FreeRTOS tasks (rendering, and the
// blink/saccade/breath state machine) to APP_CPU_NUM in Avatar::start(), so
// Core 1 was "owned by the avatar" and everything else had to stay off it.
// PortraitFace replaced that outright: it draws synchronously, from
// whichever task calls it (appTask's own loop for idle breathing, a small
// helper task for the per-message frame cycle - see mqtt_link.h's
// lipSyncTask), so nothing hardcodes a core anymore. appTask is still
// pinned to core 0 below, but now only for the same reason the app logic
// was already there - WiFi/BT stacks live on PRO_CPU, and that's also
// where TTS/wake-word/LLM-client work would hang off if this grows one.
// Core 1 just runs Arduino's own (empty) loop() and is otherwise unused.

#include <Arduino.h>
#include <M5Unified.h>
#include <U8g2lib.h>
#include <Wire.h>
#include <OneButton.h>

#include "ssd1306_display.h"
#include "portrait_face.h"
#include "speech_bubble.h"
#include "digital_clock.h"
#include "mqtt_link.h"
#include "device_settings.h"
#include "ble_config.h"
#include "secrets.h"
#include "boot.h"
#include "splash.h"
#include "rgb_led.h"
#include "jingle.h"

// SSD1306 on SDA=GPIO4, SCL=GPIO15, address 0x3C.
// SDA is on GPIO4 rather than the more usual GPIO2 because GPIO2 is a
// boot-strapping pin — the OLED's pull-up on it holds the ESP32 out of USB
// download mode ("Wrong boot mode detected (0x1b)") and flashing fails with
// the display attached. GPIO4 has no strapping role. Same wiring as the
// sibling `hello-world` panel in this folder.
#define OLED_SDA 4
#define OLED_SCL 15

// Second OLED, on its own bus rather than sharing the first one: GPIO32/33,
// driven as *software* (bit-banged) I2C, so it can sit at the default 0x3C
// address with no jumper/resistor mod needed. A negative i2c_port tells
// LGFX's Bus_I2C to use its bit-banged path (soft_i2c.inl) instead of one of
// the two hardware peripherals — see Bus_I2C.hpp's config_t comment ("e.g.
// ESP32 0=I2C_NUM_0 / 1=I2C_NUM_1 / negative=software"). GPIO32/33 avoid the
// pins already spoken for (4/15 here, boot-strapping pins 0/2/5/12) and
// aren't used elsewhere on this board. Clocked slower than the hardware bus
// (400kHz vs 800kHz) since bit-banged timing is CPU-cycle-bound and less
// forgiving at high speed.
#define OLED_TEXT_SDA 32
#define OLED_TEXT_SCL 33
#define OLED_TEXT_I2C_PORT (-1)

// Passive piezo for the per-character beep in the speech bubble (see
// SpeechBubble's onChar hook). GPIO27 avoids both OLEDs' pins above, the
// boot-strapping pins (0/2/5/12), and the flash pins (6-11).
#define PIEZO_PIN 27

// 4-pin RGB LED (common-cathode assumed: common leg to GND, each color leg
// through its own current-limiting resistor to the GPIO below). Board is a
// 30-pin ESP32 devkit with no GPIO16/17 broken out, so these three were
// picked instead — all LEDC-PWM-capable, clear of the OLED buses (4/15,
// 32/33), the piezo (27), the boot-strap pins (0/2/5/12), and M5Unified's
// reserved PortA pins (21/22). If the LED turns out to be common-anode
// instead (common leg to 3.3V), define RGB_COMMON_ANODE below to invert the
// PWM duty cycle rather than rewiring.
#define RGB_R_PIN 25
#define RGB_G_PIN 26
#define RGB_B_PIN 14
// #define RGB_COMMON_ANODE

// Multifunction push button. 4-leg tactile switches like this are a single
// SPST contact, not four independent ones, but which two legs are already
// shorted together inside the case (and so must be avoided as a pair) varies
// by part - don't assume a layout, check it with a multimeter.
//
// Correction, 2026-09-16: this used to claim the shorted pairs are always
// "diagonally opposite" corners, on the assumption that the two legs on a
// given side are permanently tied together and only the diagonal picks work
// as a switch. That's wrong for the switch actually on this board - a
// continuity check across the two same-side legs wired here (GPIO13 leg and
// GND leg) read open at rest and closed on press, i.e. a working switch
// contact, which the "same side is always shorted" assumption said should
// be impossible. Verified live 2026-09-16 by the wiring in place: pin reads
// HIGH released, LOW pressed, matching OneButton's activeLow=true below.
// OneButton (see platformio.ini) enables the internal pull-up, so the pin
// reads HIGH released and LOW pressed. GPIO13 avoids the OLED buses (4/15,
// 32/33), the piezo (27), the RGB LED (14/25/26), the boot-strapping pins
// (0/2/5/12), and the flash pins (6-11).
#define BUTTON_PIN 13

#ifdef RGB_LED_TEST
// Bench-only wiring test, built with `-D RGB_LED_TEST` (see platformio.ini)
// instead of the real app — same pattern as AVATAR_DEMO_MODE/AVATAR_FB_DUMP
// below, but standalone at setup()/loop() rather than inside appTask, since
// this needs no OLEDs/WiFi/MQTT and is meant to run before any of that is
// wired up. Remove the flag and reflash to go back to the real app.
static constexpr uint32_t kRgbPwmFreq = 5000;
static constexpr uint8_t kRgbPwmRes = 8;  // 8-bit duty: 0-255

static void rgbSetColor(uint8_t r, uint8_t g, uint8_t b) {
#ifdef RGB_COMMON_ANODE
  r = 255 - r;
  g = 255 - g;
  b = 255 - b;
#endif
  ledcWrite(RGB_R_PIN, r);
  ledcWrite(RGB_G_PIN, g);
  ledcWrite(RGB_B_PIN, b);
}

// Standard HSV(h in [0,360), s=v=1) -> RGB, for the spectrum sweep below.
static void hsvToRgb(float h, uint8_t &r, uint8_t &g, uint8_t &b) {
  float c = 255.0f;
  float x = c * (1 - fabsf(fmodf(h / 60.0f, 2) - 1));
  float rp = 0, gp = 0, bp = 0;
  if (h < 60) {
    rp = c; gp = x;
  } else if (h < 120) {
    rp = x; gp = c;
  } else if (h < 180) {
    gp = c; bp = x;
  } else if (h < 240) {
    gp = x; bp = c;
  } else if (h < 300) {
    rp = x; bp = c;
  } else {
    rp = c; bp = x;
  }
  r = (uint8_t)rp;
  g = (uint8_t)gp;
  b = (uint8_t)bp;
}
#endif  // RGB_LED_TEST

// Swapped 2026-09-15: the two physical OLED panels turned out to be mounted
// reversed relative to their wiring, so `oled` (the avatar/face panel) and
// `oledText` (bubble+clock) now each take the *other's* former pins/bus to
// put content back on the correct physical screen. GPIO4/15's hardware bus
// and GPIO32/33's bit-banged bus are unchanged as electrical facts (see the
// macro comments above) — only which content rides which bus moved. Net
// effect: the avatar now runs on the slower 400kHz bit-banged bus instead of
// the 800kHz hardware one, until the wiring itself gets corrected instead.
static SSD1306Display oled(OLED_TEXT_SDA, OLED_TEXT_SCL, 400000,
                            OLED_TEXT_I2C_PORT, 0x3C);
static SSD1306Display oledText(OLED_SDA, OLED_SCL);

// HLI boot POST + splash intro (boot.h/splash.h, ported verbatim from
// ~/Code/esp32_oled/HLI): drawn through U8g2's own I2C drivers, not through
// the LGFX `oled`/`oledText` objects above, since boot.cpp/splash.cpp draw
// directly to a U8G2& and porting them to LGFX wasn't worth it for a
// sequence that only plays once, before each panel gets handed to its real
// owner (the avatar / the clock+bubble). Named for physical position rather
// than content below, since which sequence draws where has already flipped
// once (2026-09-16: POST moved to the top panel, splash to the bottom one —
// see setup()).
//
// Correction, 2026-09-15: this used to say the two sequences "run on
// separate panels concurrently rather than one after another" — setup()
// drew both every frame in one shared while loop. That turned out to be why
// *both* were reported janky, not just the slower of the two: sharing one
// frame clock meant each sequence's own animation was throttled down to
// whatever pace the loop as a whole could sustain, which was however long
// the slower panel's send took, regardless of how fast the other one's own
// bus was. setup() below now runs them as two genuinely separate phases —
// POST alone first, then splash alone — so each phase's frame rate is
// bounded only by its own panel.
//
// U8G2_R0 on both, not U8G2_R2::R2 (180°) looked upside down on real
// hardware even though it matches M5.Display's/oledText's own
// setRotation(2) below — U8g2's rotation and LGFX's rotation(2) don't agree
// for this SSD1306 driver/panel combination. Verified live 2026-09-15.
//
// Pins/bus swapped 2026-09-15 along with `oled`/`oledText` above, for the
// same physical-panel reversal — u8g2Top must stay on whichever pins `oled`
// now uses (both drive the physically-top panel, one at boot and one at
// runtime), same for u8g2Bottom/oledText. That puts u8g2Top (POST) on
// GPIO32/33 and u8g2Bottom (splash) on GPIO4/15.
//
// u8g2Top claims the ESP32's second hardware I2C peripheral (Wire1) for
// GPIO32/33 instead of U8g2's own software/bit-banged I2C, even though that
// pair has no pre-existing hardware claim the way GPIO4/15 does — Wire1
// sits completely idle for the whole length of this phase regardless, and
// U8g2's software I2C bit-bangs through digitalWrite() per bit, which
// measured slow enough (tens of ms to send one 1024-byte frame) to be the
// actual cause of POST's own reported jank, on top of the shared-loop
// problem above. See Wire1.begin() in setup() and platformio.ini's
// U8X8_HAVE_2ND_HW_I2C flag — without it the _2ND_HW_I2C constructor below
// is a silent no-op. u8g2Bottom needs no equivalent treatment: it already
// sits on GPIO4/15's actual hardware peripheral (global Wire/I2C_NUM_0).
static U8G2_SSD1306_128X64_NONAME_F_2ND_HW_I2C u8g2Top(U8G2_R0,
                                                        U8X8_PIN_NONE);
static U8G2_SSD1306_128X64_NONAME_F_HW_I2C u8g2Bottom(U8G2_R0, U8X8_PIN_NONE,
                                                       OLED_SCL, OLED_SDA);
// The face panel's announcer - a pointer, not a plain static object, since
// it needs `oled` already init()'d before it can draw its first frame; see
// its construction in setup(), right where avatar.setFace()/init() used to
// sit.
static PortraitFace *portraitFace = nullptr;
static SpeechBubble *bubble = nullptr;
// The bubble panel's idle/default face — MqttLink switches back to this once
// a message has finished displaying (see mqtt_link.h's handleMessage()).
// Named idleClock, not clock: that shadows <time.h>'s clock() at global scope
// and fails to compile.
static DigitalClock *idleClock = nullptr;
// Real (non-RGB_LED_TEST) app's RGB status LED, on the same three pins the
// bench test above uses. begin() is called from the real setup() below;
// MqttLink is handed a pointer to this so it can light it for as long as a
// message is on screen (see mqtt_link.h's display()/rgb_led.h's start()).
static RgbLed rgbLed(RGB_R_PIN, RGB_G_PIN, RGB_B_PIN);
// Plays a short notification tune, picked per-message the same way LED color
// is (see mqtt_link.h's display()/jingle.h's Jingle::play()). Shares
// PIEZO_PIN with beepChar() below and splash's boot theme - never contends
// with either, since it only ever plays synchronously from inside
// MqttLink::display(), before that message's own typing beeps start.
static Jingle jingle(PIEZO_PIN);

// Loaded in setup(), ahead of the boot POST screen, so its NVS-backed values
// (see device_settings.h) are available for boot::begin() to show - well
// before appTask (which used to be the one loading this) even starts. Global
// rather than local to appTask for that reason; appTask just reads it.
static constexpr const char *kDefaultDeviceName = "mqttchan";
static DeviceSettings settings;

// tone() is non-blocking (LEDC-driven), so this is safe to call from inside
// SpeechBubble::show()'s per-character reveal loop without slowing it down.
static void beepChar() { tone(PIEZO_PIN, 1800, 15); }

#ifdef AVATAR_DEMO_MODE
// Placeholder for real TTS text; nihilistic one-liners for now because a
// demo bubble should at least be funny. Only used by the self-cycling demo
// loop below — real messages come from MQTT. Used to be one line per
// contract v2 "expression" value (removed 2026-09-19 - see mqtt_link.h's
// constructor comment), but the phrases never depended on that mapping for
// anything besides array length, so they just cycle on their own count now.
static const char *const kPhrases[] = {
    "Smile. The void won't notice.", "Scream away. Nothing's listening.",
    "Cheer up - nothing matters.",    "No one's driving. Never was.",
    "Rest easy. Heat death can wait.", "Just meat, doing meat things."};
static constexpr size_t kPhraseCount =
    sizeof(kPhrases) / sizeof(kPhrases[0]);

// Cycles the announcer through its own frame set for `ms` - the same thing
// mqtt_link.h's lipSyncTask does for a real message, but driven by hand
// since this demo mode has no MQTT message triggering that path. Stand-in
// for what a real TTS engine on core 0 would drive instead.
static void speakFor(uint32_t ms) {
  if (portraitFace == nullptr) return;
  portraitFace->startTalking();
  const uint32_t until = millis() + ms;
  while (millis() < until) {
    portraitFace->advanceTalkFrame();
    vTaskDelay(pdMS_TO_TICKS(150));
  }
  portraitFace->stopTalking();
}

// Ticks the announcer's idle breathing sway during a demo-loop pause -
// appTask's real for(;;) loop does this every ~50ms (see below); demoLoop()
// has no equivalent loop of its own during its plain vTaskDelay() gaps, so
// without this the face would just sit frozen between phrases.
static void idleDelay(uint32_t ms) {
  const uint32_t until = millis() + ms;
  while (millis() < until) {
    if (portraitFace != nullptr) portraitFace->tick(millis());
    vTaskDelay(pdMS_TO_TICKS(50));
  }
}
#endif

#ifdef AVATAR_FB_DUMP
// Debug aid for a headless bench: dump what is actually in the panel's
// framebuffer as ASCII, since Panel_HasBuffer keeps a readable RAM copy.
// Build with -DAVATAR_FB_DUMP to enable. Costs nothing when off. No
// suspend/resume needed around the read (unlike the old m5avatar version) -
// PortraitFace has no background draw task to race; it only ever draws
// synchronously from whichever caller invokes it.
static void dumpFramebuffer(const char *label) {
  Serial.printf("---- %s ----\n", label);
  for (int y = 0; y < 64; y += 2) {
    char row[129];
    for (int x = 0; x < 128; x++) {
      // Sample two rows per line so 64 rows fit a terminal at 1:1 aspect.
      bool on = M5.Display.readPixel(x, y) || M5.Display.readPixel(x, y + 1);
      row[x] = on ? '#' : '.';
    }
    row[128] = 0;
    Serial.println(row);
  }
}

// Same trick for the bubble panel. Nothing else writes to oledText besides
// appTask itself, which is what's calling this, so there's no concurrent
// writer to freeze.
static void dumpBubbleFramebuffer(const char *label) {
  if (bubble == nullptr) return;
  Serial.printf("---- bubble: %s ----\n", label);
  for (int y = 0; y < 64; y += 2) {
    char row[129];
    for (int x = 0; x < 128; x++) {
      bool on = oledText.readPixel(x, y) || oledText.readPixel(x, y + 1);
      row[x] = on ? '#' : '.';
    }
    row[128] = 0;
    Serial.println(row);
  }
}
#endif

#ifdef AVATAR_DEMO_MODE
// Self-cycling bench demo: no network needed, just the two OLEDs. Build with
// -DAVATAR_DEMO_MODE to get this instead of the real MQTT-driven behavior
// below — same idea as -DAVATAR_FB_DUMP, a flag-gated mode for bench testing.
static void demoLoop() {
  size_t i = 0;
  for (;;) {
    // Swaps the announcer to a new random face each pass - the same call
    // MqttLink::revertToIdle() makes after a real announcement.
    if (portraitFace != nullptr) portraitFace->pickRandom();
    if (bubble != nullptr) {
      bubble->show(kPhrases[i % kPhraseCount]);
    }

    char label[16];
    snprintf(label, sizeof(label), "phrase %u",
             (unsigned)(i % kPhraseCount));

    Serial.printf("[core %d] %-10s heap=%6u draw=core %d\n", xPortGetCoreID(),
                  label, (unsigned)ESP.getFreeHeap(), APP_CPU_NUM);

#ifdef AVATAR_FB_DUMP
    delay(400);
    dumpFramebuffer(label);
    dumpBubbleFramebuffer(label);
#endif

    // Every third phrase, babble for a bit so the portrait's own frames
    // cycle (see speakFor()).
    if (i % 3 == 2) {
      speakFor(1500);
      idleDelay(1000);
    } else {
      idleDelay(2500);
    }
    i++;
  }
}
#endif
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
void loop() {
  // Intentionally empty. Arduino's loopTask runs on core 1; app work goes in
  // appTask on core 0 instead - see the file-header comment.
  vTaskDelay(pdMS_TO_TICKS(1000));
}
#endif  // RGB_LED_TEST

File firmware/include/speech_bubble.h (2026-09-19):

// Renders spoken text as a word-wrapped, bordered "speech bubble" on a
// second panel, independent of the avatar's own M5.Display. See
// ssd1306_display.h for why the avatar needs M5.Display to itself; this
// class just draws directly to whatever M5GFX device it is given.
#pragma once

#include <Arduino.h>
#include <M5GFX.h>
#include <functional>
#include <utility>
#include <vector>

class SpeechBubble {
 public:
  // onChar, if given, fires once per revealed non-space character — the hook
  // for a per-character beep. Baked in at construction rather than passed to
  // show() so every caller (demo mode's canned phrases, MQTT mode's live
  // text) gets it for free.
  explicit SpeechBubble(M5GFX *display, std::function<void()> onChar = nullptr)
      : display_(display), onChar_(std::move(onChar)) {}

  // 1 (default) is the original small GLCD size this class was built around;
  // 2 doubles both glyph dimensions ("Large" in the display settings). Takes
  // effect on the next show() - textSize_ is only read there, so a message
  // already typing out finishes at whatever size it started at.
  void setTextSize(uint8_t size) { textSize_ = size; }

  // Reveals text one character at a time, typewriter-style. Lines are
  // wrapped up front (wrapping needs the whole word to measure it, so it
  // can't be decided mid-reveal) and then typed out line by line. Runs on
  // whatever task calls it — this blocks for roughly strlen(text) *
  // charDelayMs, which is the point: it paces itself to be readable rather
  // than dumping the whole bubble in one frame. 45ms lands around a slower,
  // more deliberate pace; drop it if a phrase is long enough to feel sluggish.
  //
  // abortRequested, if given, is polled once per character (i.e. about once
  // per charDelayMs — the same cadence callers normally tick an input device
  // at) and stops the reveal early when it returns true, leaving whatever's
  // been typed so far on screen. MqttLink uses this so a button click can
  // interrupt a long message instead of waiting for it to finish.
  void show(const char *text, uint32_t charDelayMs = 45,
            std::function<bool()> abortRequested = nullptr) {
    // Reasserted here, not just at construction: DigitalClock draws to this
    // same display between messages and leaves its own (much larger)
    // setTextSize() in place, which wrapLines()'s width math below would
    // otherwise inherit and wrap/print far too large to read.
    display_->setTextColor(TFT_WHITE, TFT_BLACK);
    display_->setTextSize(textSize_);
    // Word-wrap by hand below; the built-in wrap breaks mid-word.
    display_->setTextWrap(false, false);

    display_->startWrite();
    display_->fillScreen(TFT_BLACK);
    display_->drawRoundRect(0, 0, display_->width(), display_->height(), 6,
                             TFT_WHITE);

    // Scales with textSize_ - the base GLCD cell is 8px tall, so "Large"
    // (textSize_ == 2) needs twice the row pitch or lines would overlap.
    const int lineHeight = kBaseLineHeight * textSize_;
    // Lines beyond what fits inside the border scroll the content area
    // upward one row at a time instead of typing off the bottom of the
    // screen unseen — see scrollRect below for why this only affects text,
    // not the border. maxLines is rounded down, so lineHeight always
    // divides the scroll region evenly and a scroll never leaves a sliver
    // of the previous line's pixels behind.
    const int maxLines =
        (display_->height() - kTopMargin - kMargin) / lineHeight;
    const int scrollHeight = maxLines * lineHeight;
    // setScrollRect only affects scroll() below, not normal drawing/clipping,
    // so this can be set once up front without touching fillScreen/
    // drawRoundRect above or the per-character prints below.
    display_->setScrollRect(kMargin, kTopMargin,
                             display_->width() - 2 * kMargin, scrollHeight);

    int cursorY = kTopMargin;
    std::vector<String> lines = wrapLines(text);
    for (size_t lineIndex = 0; lineIndex < lines.size(); lineIndex++) {
      if (lineIndex > 0) {
        if (static_cast<int>(lineIndex) < maxLines) {
          cursorY += lineHeight;
        } else {
          // Screen's full: shift everything already shown up by one row
          // rather than growing cursorY past the border. scroll() runs its
          // own nested startWrite()/endWrite(), which — same as the
          // per-character prints below — won't auto-flush to the physical
          // OLED while show()'s outer transaction is still open, hence the
          // explicit display() call.
          display_->scroll(0, -lineHeight);
          display_->display();
        }
      }
      const String &line = lines[lineIndex];
      // Explicit wipe of this row's own rect before drawing into it, rather
      // than trusting the one whole-screen fillScreen() above plus scroll()'s
      // own vacated-strip fill to have left it spotless. Belt-and-suspenders
      // for the "second line garbled at Large text size" report (2026-09-19,
      // not reproduced in a RAM-shadow-buffer dump taken after a real
      // multi-scroll run on the board - see git history for that dump - so
      // this closes the most plausible gap rather than a confirmed root
      // cause): cheap at this size, and it can only help.
      display_->fillRect(kMargin, cursorY, display_->width() - 2 * kMargin,
                          lineHeight, TFT_BLACK);
      display_->setCursor(kMargin, cursorY);
      for (size_t i = 0; i < line.length(); i++) {
        display_->print(line[i]);
        // Panel_SSD1306 is a Panel_HasBuffer: draws land in a RAM shadow
        // buffer and only reach the physical OLED when the dirty rect is
        // flushed. That normally happens on the outermost endWrite(), which
        // here is the one at the end of the whole message — so without this,
        // every character lands in the buffer at the paced delay below but
        // the screen shows nothing until the last one, and the message
        // appears to pop in all at once. display() pushes just the changed
        // columns now instead of waiting.
        display_->display();
        if (onChar_ && line[i] != ' ') onChar_();
        vTaskDelay(pdMS_TO_TICKS(charDelayMs));
        if (abortRequested && abortRequested()) {
          display_->endWrite();
          return;
        }
      }
    }
    display_->endWrite();
  }

  void clear() { display_->fillScreen(TFT_BLACK); }
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

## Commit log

2026-09-14 Add MQTT-driven mode: avatar/bubble now driven by avatar/say messages
    Replaces the self-cycling demo as the default build with a real MQTT
    client (mqtt_link.h) that subscribes to a topic and drives the avatar
    expression + speech bubble from incoming {text, expression} JSON,
    published by a new avatar-brain service on osmo. Old demo behavior is
    preserved behind -DAVATAR_DEMO_MODE for bench testing without a broker.
    [main.cpp, mqtt_link.h, speech_bubble.h]
2026-09-15 Add BLE config service, device settings, and mqttchan.kev.nz control page
    BleConfigService exposes WiFi/MQTT/display settings and a test-message
    path over a NimBLE GATT service, backed by DeviceSettings (NVS-persisted,
    partial-update). DigitalClock's timezone and MqttLink's message
    display/hold behavior are now runtime-configurable through the same path.
    docs/index.html (served as mqttchan.kev.nz via GitHub Pages, mirroring
    kev.nz's setup) is a Vue page that sends messages and edits these
    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
    [partitions_huge_app.csv]
2026-09-15 Simplify control page timezone field to a single dropdown
    Drop the raw POSIX TZ string input in favor of just the preset
    dropdown - the TZ string format isn't user friendly. A device with a
    non-preset TZ string still shows up as a selectable "Current (...)"
    option instead of being silently dropped.
2026-09-15 Add HLI boot/splash intro, fix BLE re-advertise and MQTT thread safety
    - Port a retro 286-BIOS POST sequence (boot.h/.cpp) and synthwave splash
    intro (splash.h/.cpp) from ~/Code/esp32_oled/HLI, with shared drawing
    primitives (ui.h/.cpp) and brand strings (brand.h) split out. Each panel
    runs its sequence as its own phase in setup() before being handed to its
    runtime owner (avatar / clock+bubble).
    - Fix the two physical OLED panels being wired reversed relative to their
    content, and speed up POST's u8g2Top panel by claiming the ESP32's second
    hardware I2C peripheral instead of bit-banged I2C.
    - BleConfigService: call advertiseOnDisconnect(true) so the device resumes
    advertising a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
    [main.cpp, mqtt_link.h]
2026-09-16 Add RGB status LED, notification jingles, and button interactions
    Messages can now carry an "led"/"blink"/"jingle" field alongside
    text/expression, drive a 3-pin RGB LED and play a short tune before
    typing starts. A push button dismisses or replays the current/last
    message, and reveals a "what am I connected to" summary on demand
    instead of showing it automatically at boot. Also blanks the idle
    clock while unsynced (replacing the "--:--" placeholder) in favor of
    a startup jingle, and reworks splash.cpp's boot theme onto a
    Hirajoshi scale.
    [main.cpp, mqtt_link.h, rgb_led.h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]
2026-09-16 Add configurable message text size, device name, and boot status display
    Also hide the control page's messaging/settings panels until a Bluetooth
    device is actually connected, and keep the bubble panel showing status
    text through the WiFi/MQTT/SNTP connect sequence instead of going blank.
2026-09-16 Delay startup bubble until after the boot jingle finishes
    Play the boot jingle before showing "Connecting to <ssid>", with a
    1s pause after it, instead of firing the jingle at the same moment
    the bubble starts typing.
    Also fixes a pre-existing build break: settings.load() was missing
    the defaultMessageTextSize argument added when messageTextSize was
    introduced.
    [main.cpp]
2026-09-17 Restructure as a monorepo, add contract v2 and the TypeScript API layer
    Collapses the firmware, the broker config and a new services layer into one
    repository, and puts an API between message sources and the broker.
    Layout: firmware moves to firmware/ (flash with `cd firmware && pio run -t
    upload`), broker/ comes from ~/Homelab/osmo/mosquitto unchanged, services/ is
    new, docs/ stays at the root for GitHub Pages. ~/Homelab is not a git
    repository, so nothing was lost in the move; stubs there point here.
    Contract v2, backward compatible in both directions:
    - expression is matched with strcasecmp, so lowercase is canonical and the
    capitalized spellings still work. Previously "happy" silentl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
    [partitions_huge_app.csv]
2026-09-17 Match jingle names case-insensitively too
    Contract v2 made expression and led case-insensitive, which left jingle as the
    only field that still cared - and left a comment claiming it followed 'the same
    convention as led/expression', which was no longer true. One odd field out is a
    trap for whoever hits it, not a convention worth keeping.
    [mqtt_link.h]
2026-09-17 Record contract v2 hardware verification and the osmo deploy
    Flashed and checked against serial on the real board, with a negative control
    so that a silent log means parsed rather than unobserved: the v2 forms
    (lowercase expression, hex led, mixed-case jingle) are silent, the pre-v2
    spellings still are too, and a deliberately bad payload warns on all three
    fields. Shorthand hex is rejected rather than guessed at.
    Also deployed services/api to osmo and removed the superseded avatar-brain
    container. Its source directory is left in place there, so that is reversible.
    Corrects the root README, which said contract v2 was written but not flashed.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
2026-09-17 Sleep both OLED panels overnight, waking them for real messages
    Between midnight and 07:00 the panels are powered down with the SSD1306
    sleep command rather than left showing an idle clock and resting face,
    which previously lit the room all night unread.
    A real message still wakes both panels for as long as it is on screen
    (wakeForMessage/resleepIfNight, around display()/revertToIdle()), so the
    window suppresses the *resting* state rather than notifications.
    Two thresholds deliberately differ: isScreenOffTime() starts at midnight
    while isNighttime() starts at 23:00. The latter governs only the resting
    face's expression, and the two do not have to share a boundary.
    resleepIfNight() recompu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
    [main.cpp, mqtt_link.h]
2026-09-17 Add the ZQN flights feed, the first real data source
    feeds/flights announces arrivals and departures at one configured airport
    - ZQN, via three environment variables - from live ADS-B. There is no
    arrivals API in play, only where every aircraft is right now, so a
    movement is an edge: the same airframe on the ground at the field after
    being airborne, or the reverse.
    Four rules stop that edge firing when nothing happened, each one an
    observed false positive rather than a hypothetical:
    - Non-transponder contacts (type ending _nt) are ignored. NZQN's 30nm
    circle holds six, two self-identifying as TWR; they are ADS-B ground
    infrastructure sitting permanently at alt_baro "ground" and otherwi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
2026-09-17 Record the flights feed confirmed live on real traffic
    Deployed to osmo and confirmed end to end 2026-09-18, 09:20 NZST:
    "ZKICH left ZQN" published from the deployed container, one message, no
    duplicate from the aircraft's subsequent climb snapshots, nothing
    dropped, queue drained, device connected throughout.
    This closes the gap both READMEs flagged. A departure was the one path
    with only unit tests behind it - the arrival side had been validated
    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
2026-09-18 Consolidate flights feed refinements and related service updates
    Updates to the flights feed integration, services configuration, and documentation following live traffic testing. Adds temperature data source structure and new routing support.
    [double oled case.stl, single oled case.stl, zqn_case_lid.stl]
2026-09-19 Add idle blink/nod, a quiet beep+green LED for sensor readings, and two display fixes
    Portrait idle animation now punctuates the breathing sway with a periodic
    blink (flash to the character's own second frame) or, for the two
    single-frame characters, a small head-nod dip instead - every character now
    gets some idle motion beyond the sway.
    sensor.reading (today only ha-temperature's room readings) gets a new single
    "beep" jingle and a green LED instead of being fully silent - required also
    removing presentationFor()'s blanket "low priority strips the jingle" rule,
    since the feed always sends that kind at low priority.
    Also: SpeechBubble now explicitly wipes each line's own rect before drawi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
    [main.cpp, mqtt_link.h, portrait_face.h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]
2026-09-19 Make the idle blink universal instead of substituting a nod for two characters
    The previous pass gave the two single-frame characters (index 44/portrait
    112, 66/portrait 156) a head-nod in place of a blink, since they have no
    second frame to flash to - not what was asked for. gen_portraits.py now
    synthesizes one for each: closes the eye region (hand-picked per character)
    and cuts a thin line back through it, the same flat-icon convention this
    pack already uses elsewhere. Every character now has a real frame 1 to
    blink to, so PortraitFace::startBlink() no longer needs a frameCount==1
    fallback at all.
    [portrait_face.h]
2026-09-19 Fix idle blink actually opening some characters' mouths
    The previous fix synthesized a real second frame for the two characters with
    no frame 1 at all, but left every other character blinking by flashing to
    its own frame 1 - which, on a live board, turned out to be a mouth-open
    frame for a large fraction of the pack (frame 1+ are talk-cycle mouth-flap
    frames, not blink variants). Idle was visibly opening its mouth instead of
    blinking. The reuse itself was the bug, not just the two-character exception
    list around it.
    gen_portraits.py now synthesizes a `blink` frame for every one of the 99
    characters, hand-positioned per character against its own frame-0 art and
    QA'd via a rendered contact sh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
    [portrait_face.h]
2026-09-19 Add contract v3, screen-power scheduling, the sky feed, and a bigger jingle catalog
    - Contract v3: drop "expression" entirely - it stopped driving anything the
    moment the portrait pack replaced m5avatar's procedural eyes/mouth, so this
    removes the vestigial parse/validate-only field and its tests.
    - Screen power: a configurable overnight window that sleeps both OLED panels,
    with an option to wake for an incoming message.
    - New feeds/sky: sun/moon/planet digest, aurora Kp alert, and MetService
    severe weather warnings for Queenstown - wired into docker-compose and
    .env.example alongside the existing feeds.
    - Jingle catalog: five new tunes (coin, oneup, stageclear, descend, trill -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
    [main.cpp, mqtt_link.h, portrait_face.h]
